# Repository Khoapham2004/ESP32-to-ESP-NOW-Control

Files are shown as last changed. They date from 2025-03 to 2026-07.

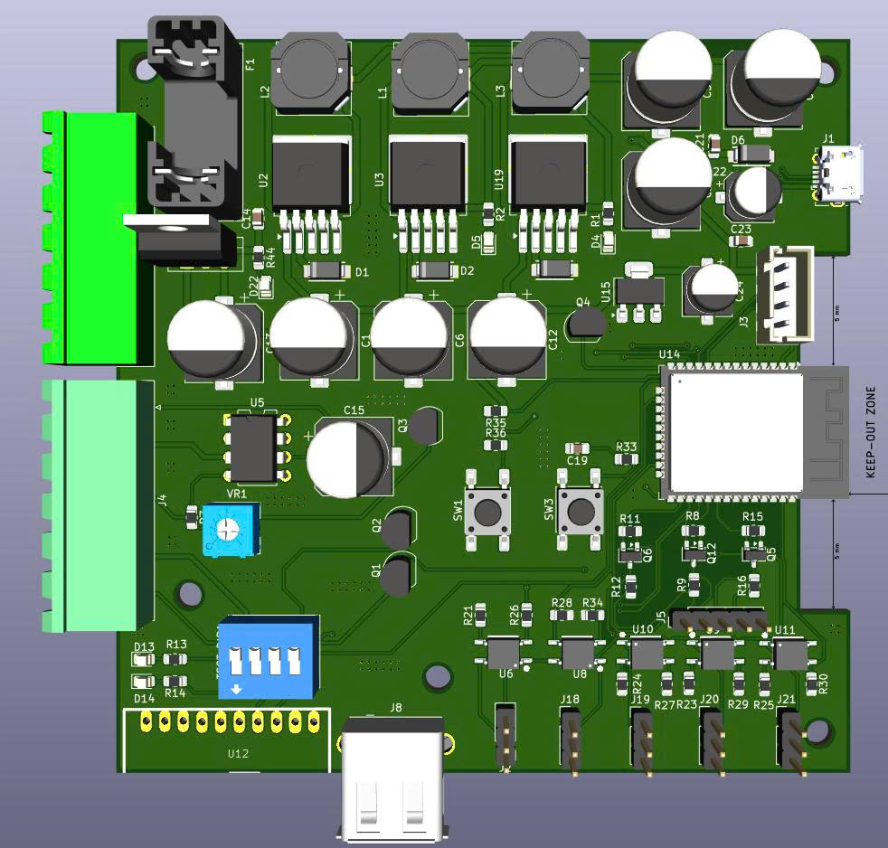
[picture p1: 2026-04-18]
EV_Smart_2026/RX_esp_now/pic1_RX.jpg

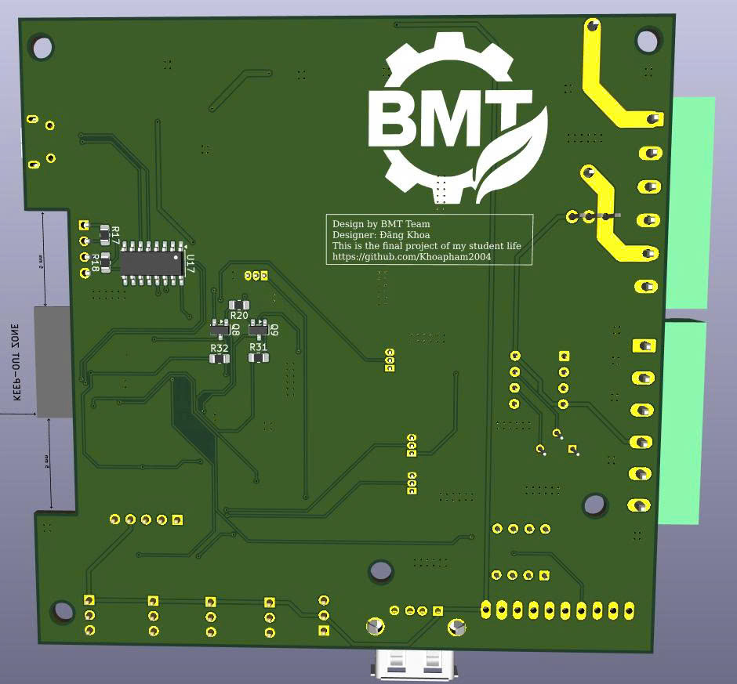
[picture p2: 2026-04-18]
EV_Smart_2026/RX_esp_now/pic2_RX.jpg

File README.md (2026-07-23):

The second repository contains the hardware design of the robot. It is mostly based on the 2025 version, with updated sensors, the BTS signal removed from the previous design, and a PCB that primarily uses SMD components for improved compactness and reliability.




The following slide presents the control board developed for the 2026 project.





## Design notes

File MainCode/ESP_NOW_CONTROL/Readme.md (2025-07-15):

1. Use source Get_ID_esp32.cpp get ID from esp receiver . Then we have a const ID EX: 00:4B:12:8E:79:D0.
2. Change the appropriate ID address in the transmission code.



Then Upload code for esp trans.

3. Upload again esp receiver by the esp_now_receive.cpp.
   
NOTE : 
+ if you want to know how it work you can visit file video.mp4 and circuit design in KICAD
+ This project is implemented on PlatformIO in VSCode, and the circuit is designed in KiCAD.
+ This project also have basic autonomous driving , basing on mpu6050 and ultrasonic sensor control steering system through 2 pid

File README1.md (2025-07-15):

# ESP32-to-ESP-NOW-Control
This project uses ESP-NOW communication between two ESP32 boards to control both a steering system and a motor. The sender reads input from a potentiometer (or joystick) and transmits the data wirelessly. The receiver processes the signals to adjust a servo motor for steering and control the speed and direction of a DC motor. The system ensures precise control by mapping the input values to appropriate ranges, with calibration adjustments for accurate steering and smooth motor operation.
If you want to learn more details, please watch the video.




  NOTE: 
  + Because when WiFi is enabled, only ADC1 can be used, so I cut the Lx wire from the joystick and re-soldered it to the output pin of the potentiometer on pin 32.(for trans circuit)
  + Due to some confusion, the circuit using the IC555 for the turn signal is not accurate. For the capacitor, a 110uF should be used, and the trigger pins should use TX2 and RX2 on the ESP32 pin 30.(for receiver circuit)
    


For the pre-built setups, I also integrated an autonomous vehicle with image processing using Python into the project.You can see the results in the video Autodriving-pythone.mp4, which also uses a Raspberry Pi.

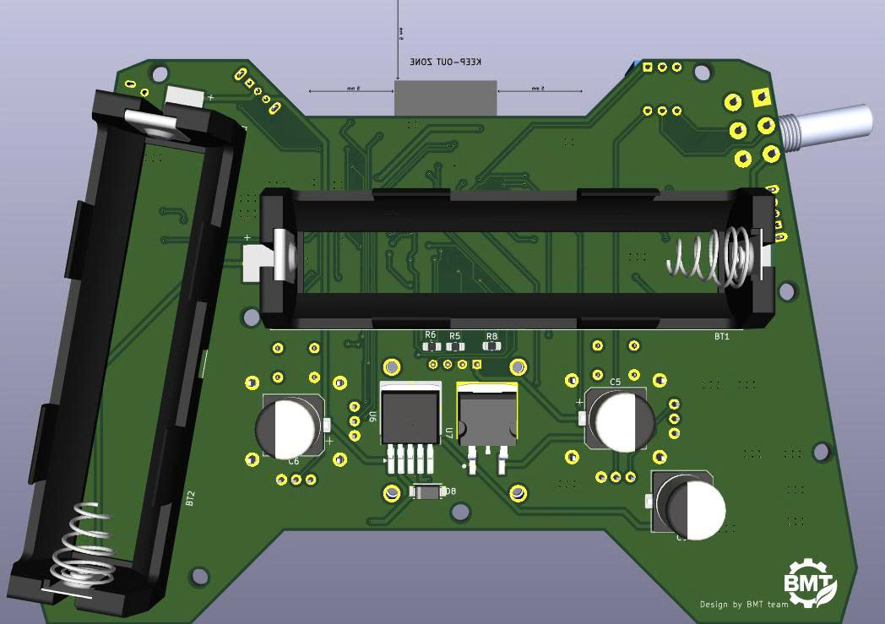
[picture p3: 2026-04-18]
EV_Smart_2026/TX_esp_now/pic2_TX.jpg

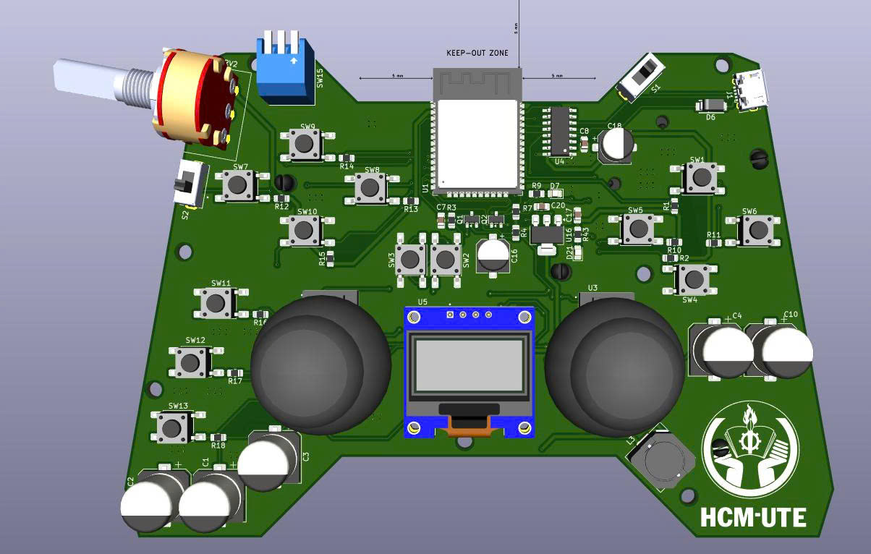
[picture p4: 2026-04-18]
EV_Smart_2026/TX_esp_now/pic1_TX.jpg

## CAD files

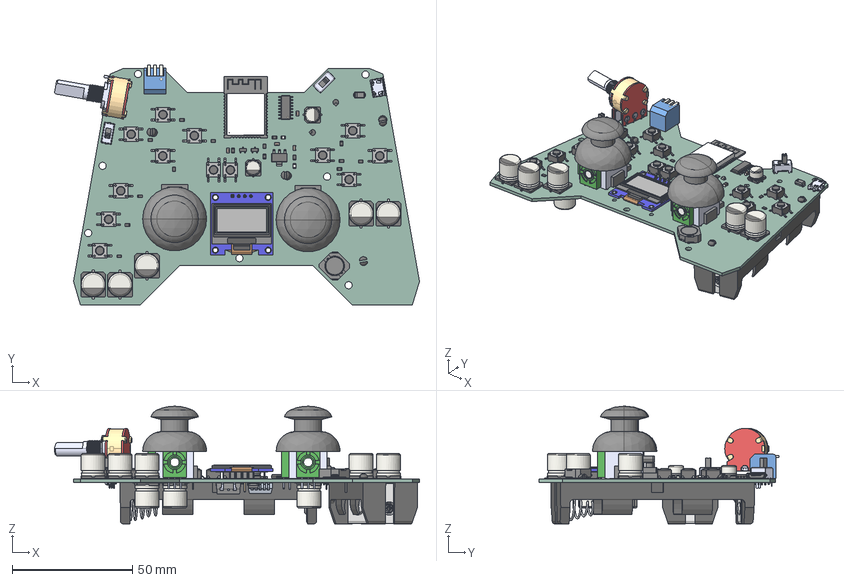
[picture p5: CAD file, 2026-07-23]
Control_PCB_2026/ps.step
152.1 x 100.1 x 49.0 mm
ESP32-WROOM-32D
CP_Elec_10x10.5 x 8
CDRH104R-100NC--3DModel-STEP-269445
10118194-0001LF--3DModel-STEP-269445
R_0805_2012Metric x 20
SW_DIP_SPSTx03_Piano_10.8x9.18mm_W7.62mm_P2.54mm
COM-09032 x 2
SW_Push_1P1T_NO_E-Switch_TL3301NxxxxxG x 13
SOT-23 x 2
CP_Elec_6.3x5.4 x 2
C_0805_2012Metric x 4
SOIC-16_3.9x9.9mm_P1.27mm
SS54-HF x 2
SS12D07VG4 x 2
SOT-223
DM-OLED096-636_Module
DM-OLED096-636_Panel
LED_0805_2012Metric x 2
KLS4-WH148-1B-4F-L20--3DModel-STEP-269445
L7805ACD2T-TR
ps 1.63.1
ps_PCB

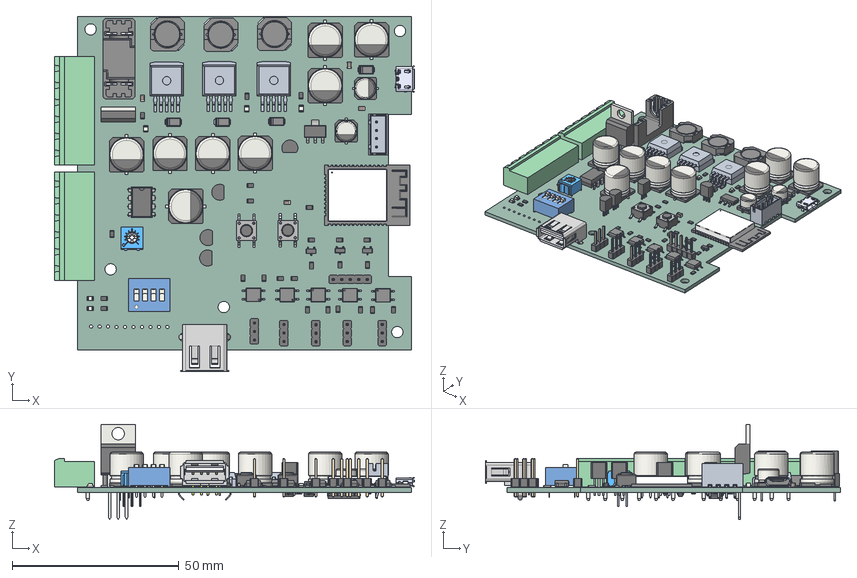
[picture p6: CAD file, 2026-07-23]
PCB_EV2026/ev_smart.step
107.9 x 106.5 x 28.5 mm
C_0805_2012Metric x 4
ev_smart 1.2
EL357N-G--3DModel-STEP-510211 x 5
R_0805_2012Metric x 30
TO-92_Inline x 4
CP_Elec_6.3x5.4 x 2
CP_Elec_10x10.5 x 8
ev_smart 1.13.1 x 3
LED_0805_2012Metric x 5
PinHeader_1x03_P2.54mm_Vertical x 5
ZX62D-B-5P8--3DModel-STEP-56544
ESP32-WROOM-32D
SS54-HF x 4
CDRH104R-100NC--3DModel-STEP-269445 x 3
SOT-23-3 x 3
PhoenixContact_MSTBA_2,5_6-G-5,08_1x06_P5.08mm_Horizontal x 2
USB-A-S-TH_S
USB-A-S-W-TH_B
USB-A-S-TH_P
PinHeader_1x05_P2.54mm_Vertical
TO-220-3_Vertical
SOT-223
DIP-8_W7.62mm
SW_Push_1P1T_NO_E-Switch_TL3301NxxxxxG x 2
3362P-1-105LF
SW_DIP_SPSTx04_Slide_9.78x12.34mm_W7.62mm_P2.54mm
SOIC-16_3.9x9.9mm_P1.27mm
SOT-23 x 2
ev_smart_PCB

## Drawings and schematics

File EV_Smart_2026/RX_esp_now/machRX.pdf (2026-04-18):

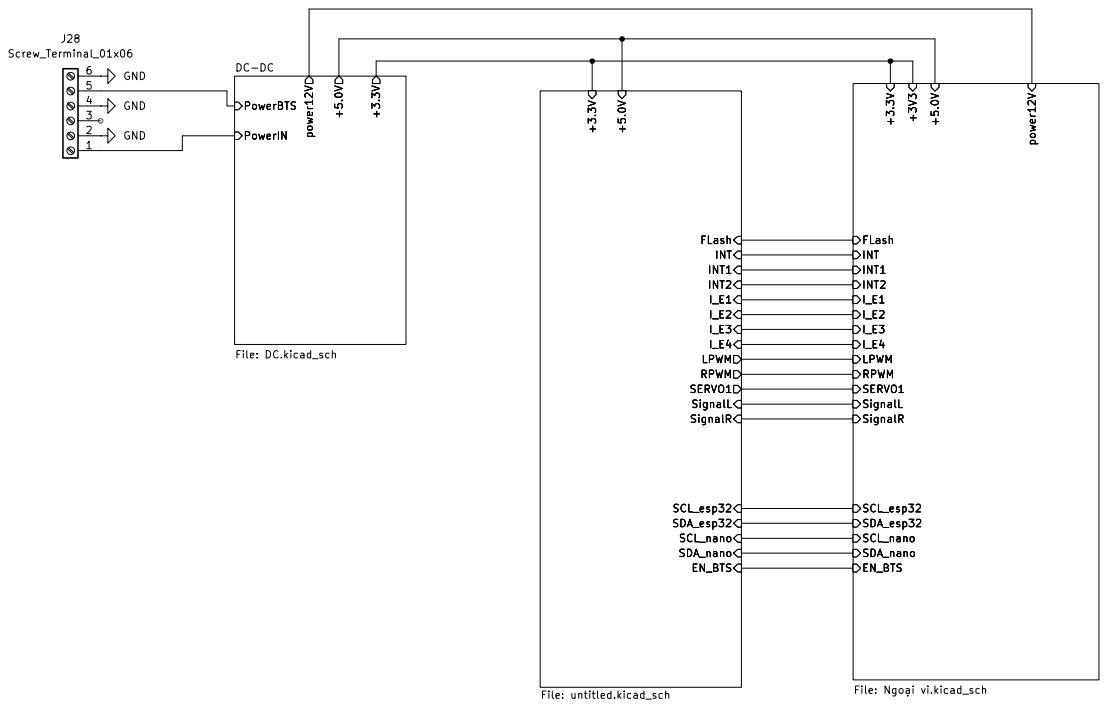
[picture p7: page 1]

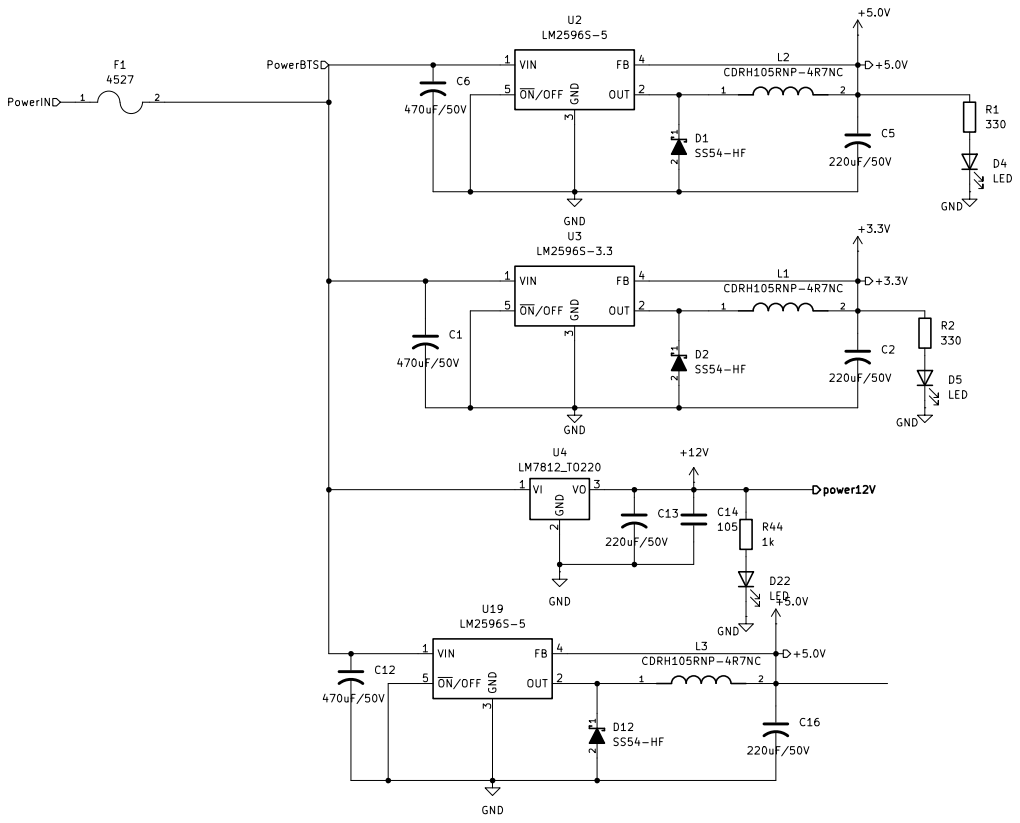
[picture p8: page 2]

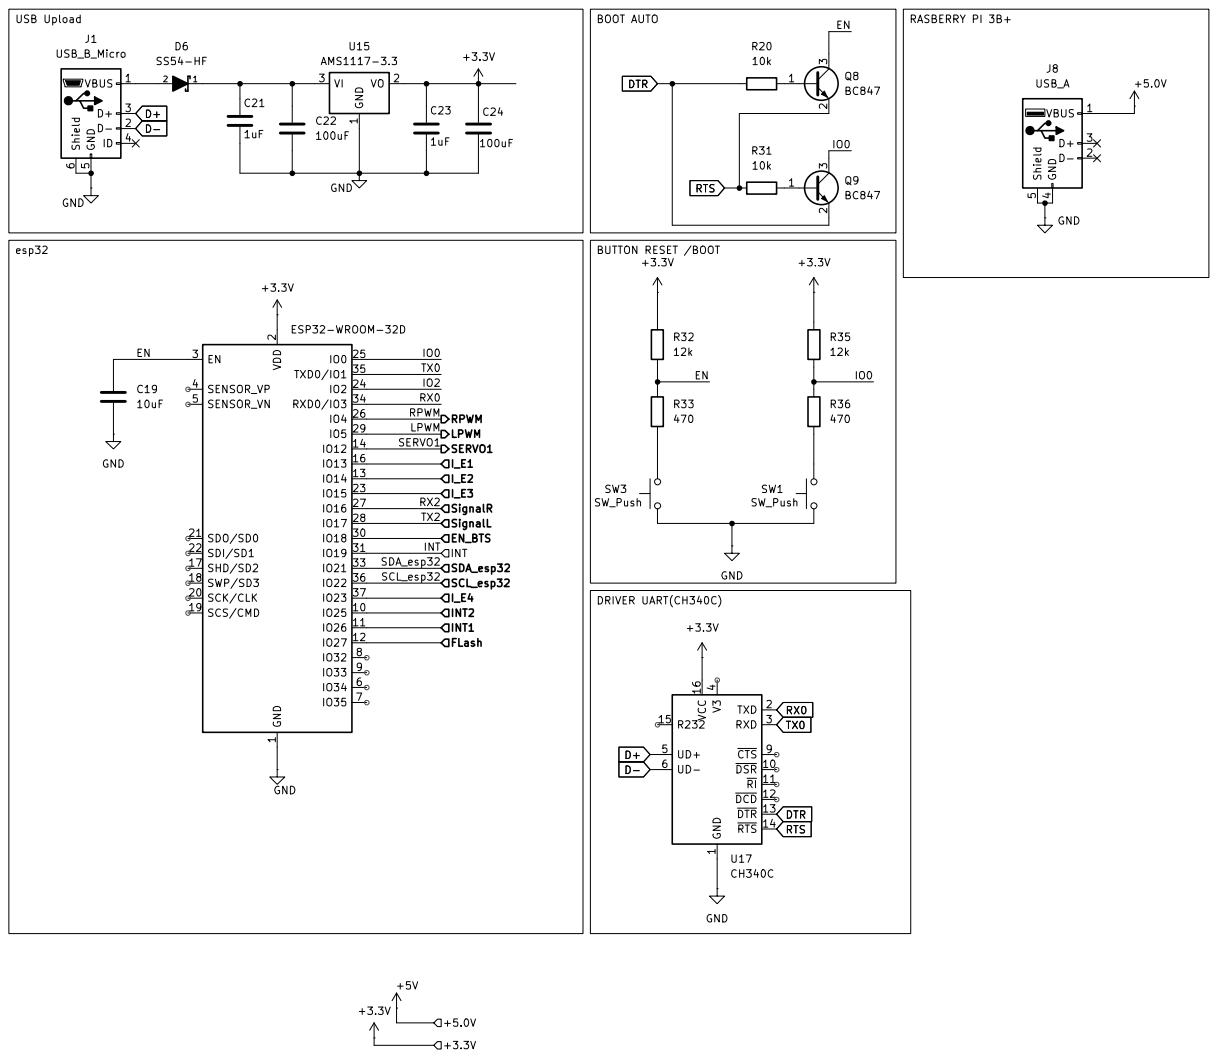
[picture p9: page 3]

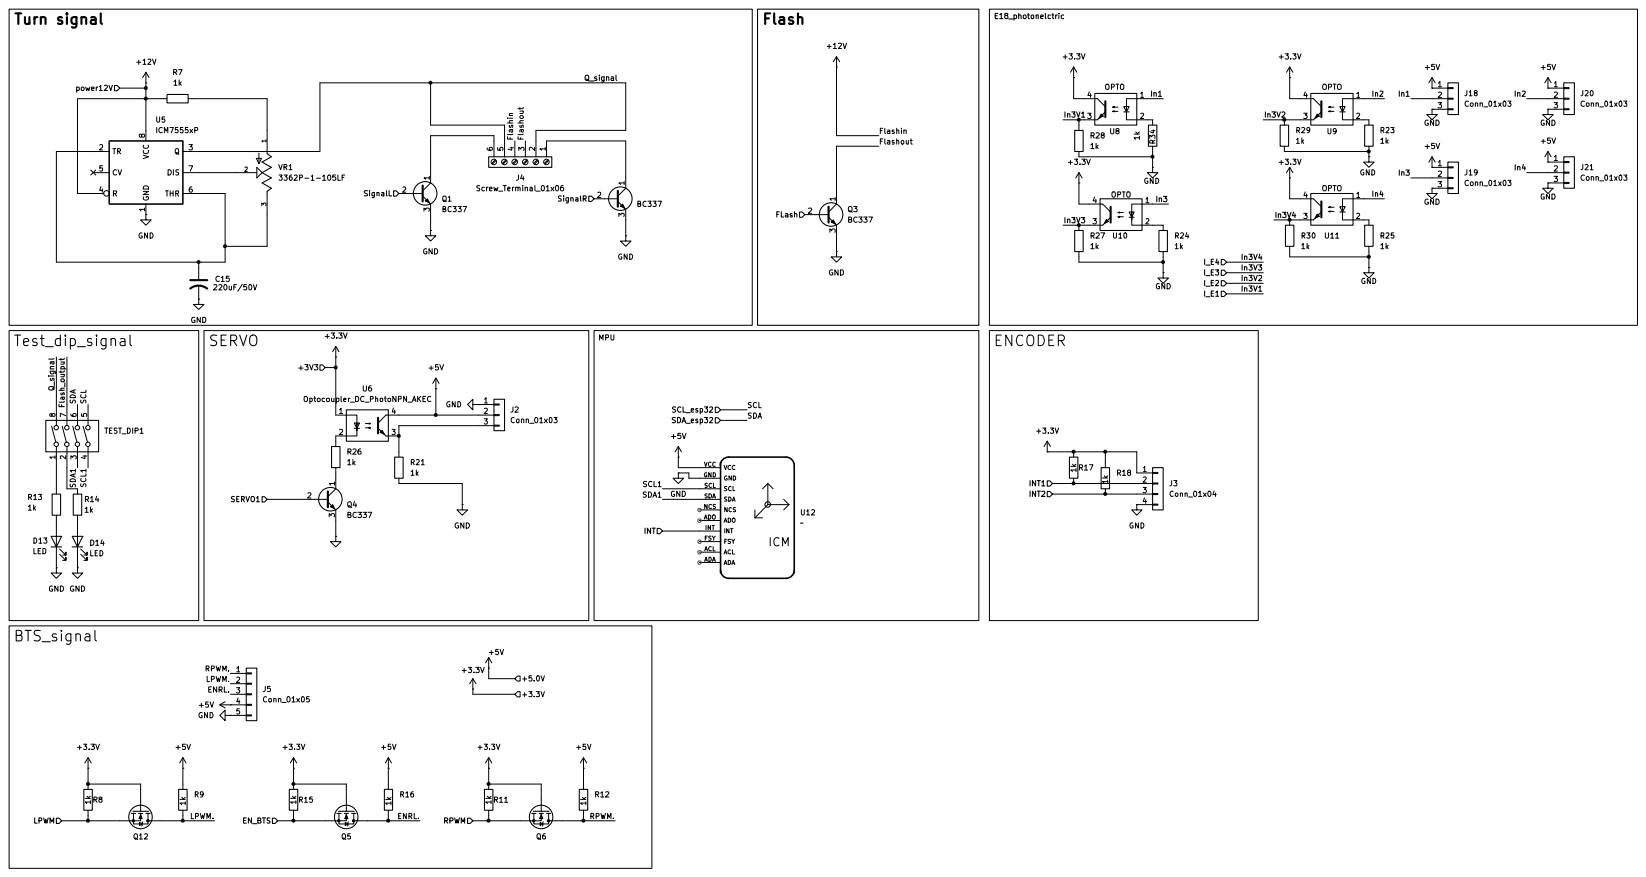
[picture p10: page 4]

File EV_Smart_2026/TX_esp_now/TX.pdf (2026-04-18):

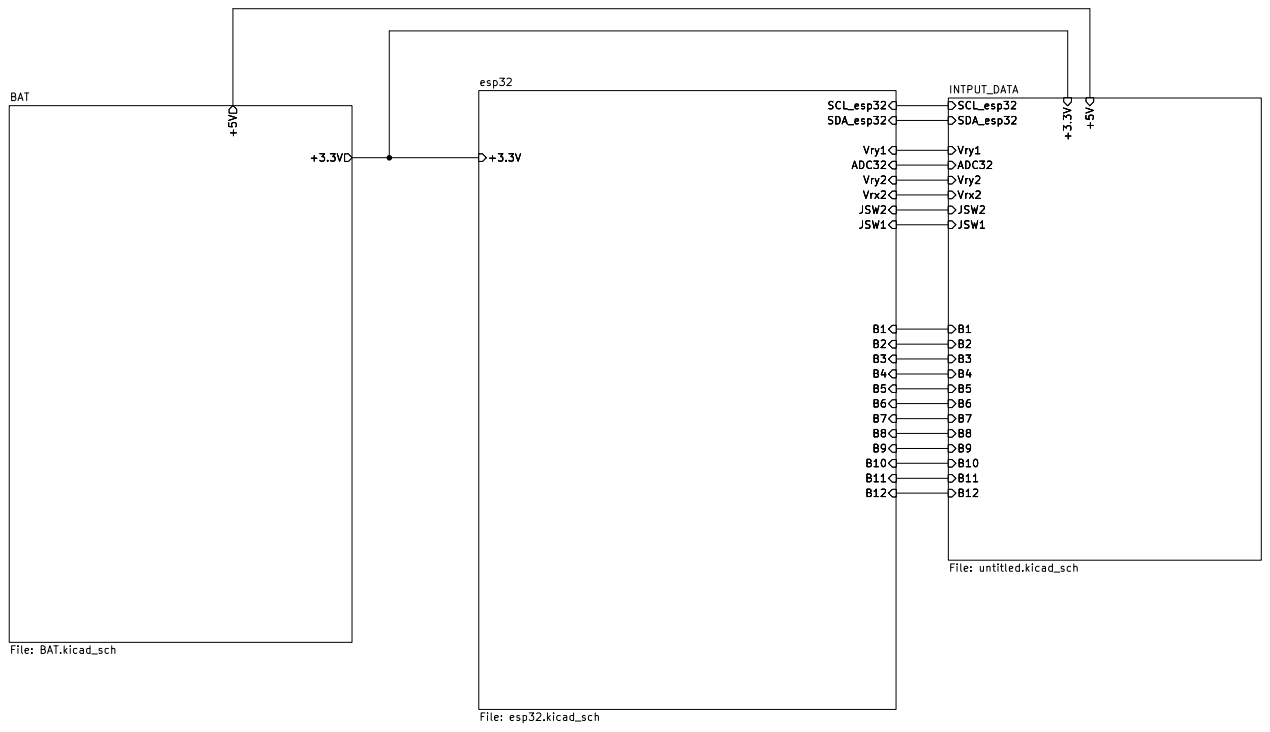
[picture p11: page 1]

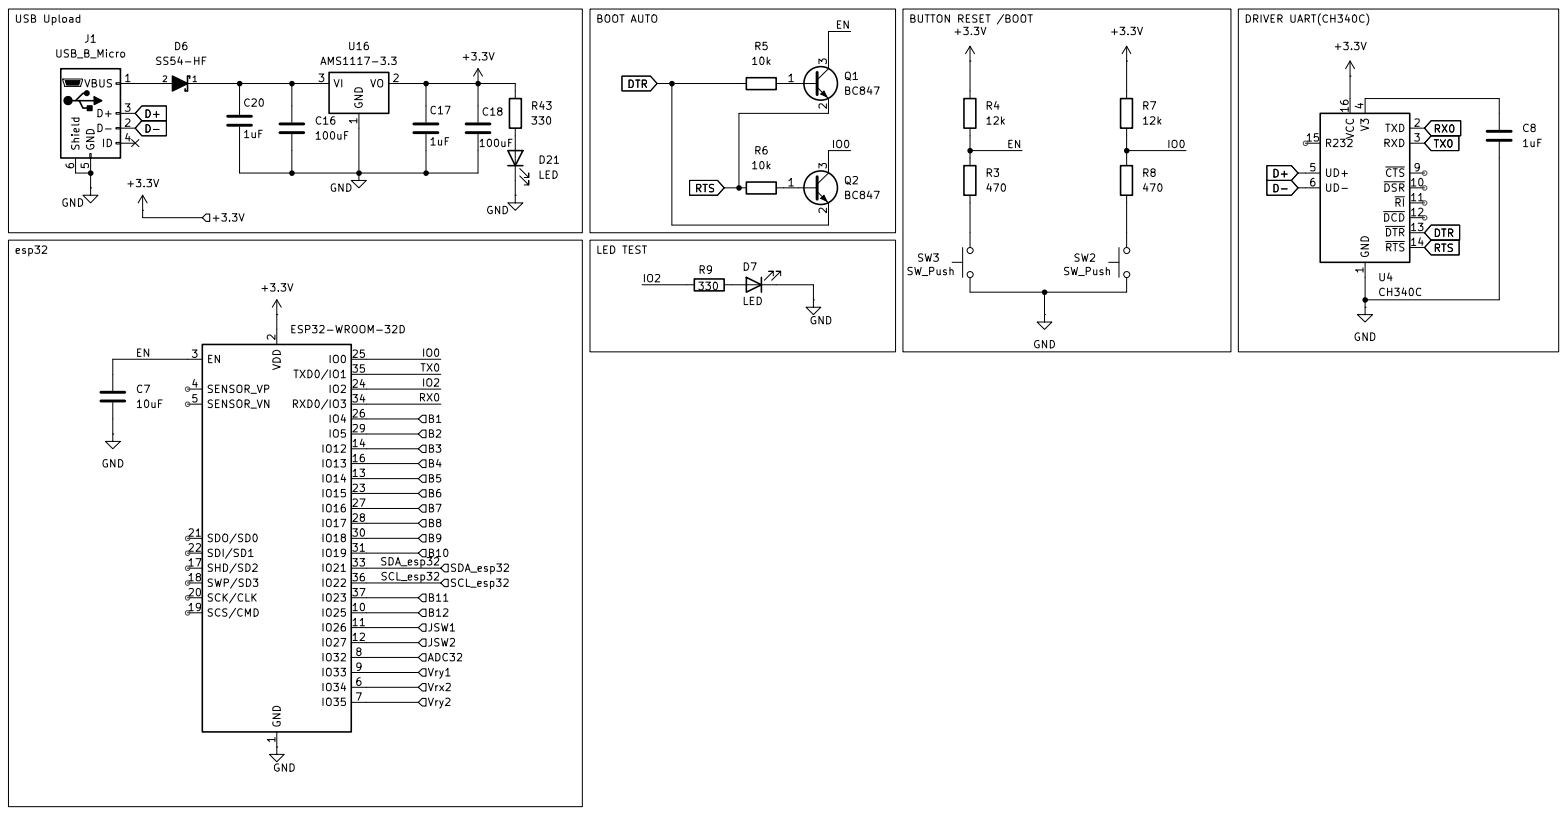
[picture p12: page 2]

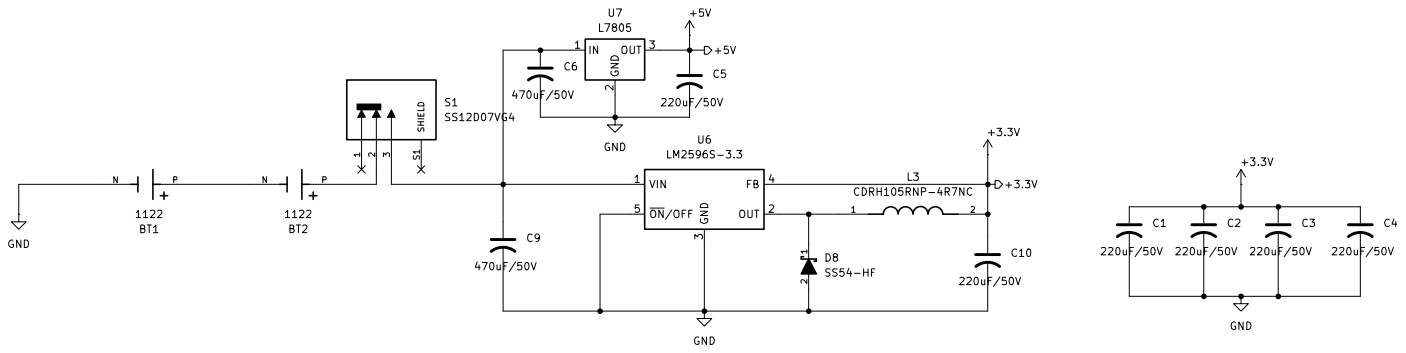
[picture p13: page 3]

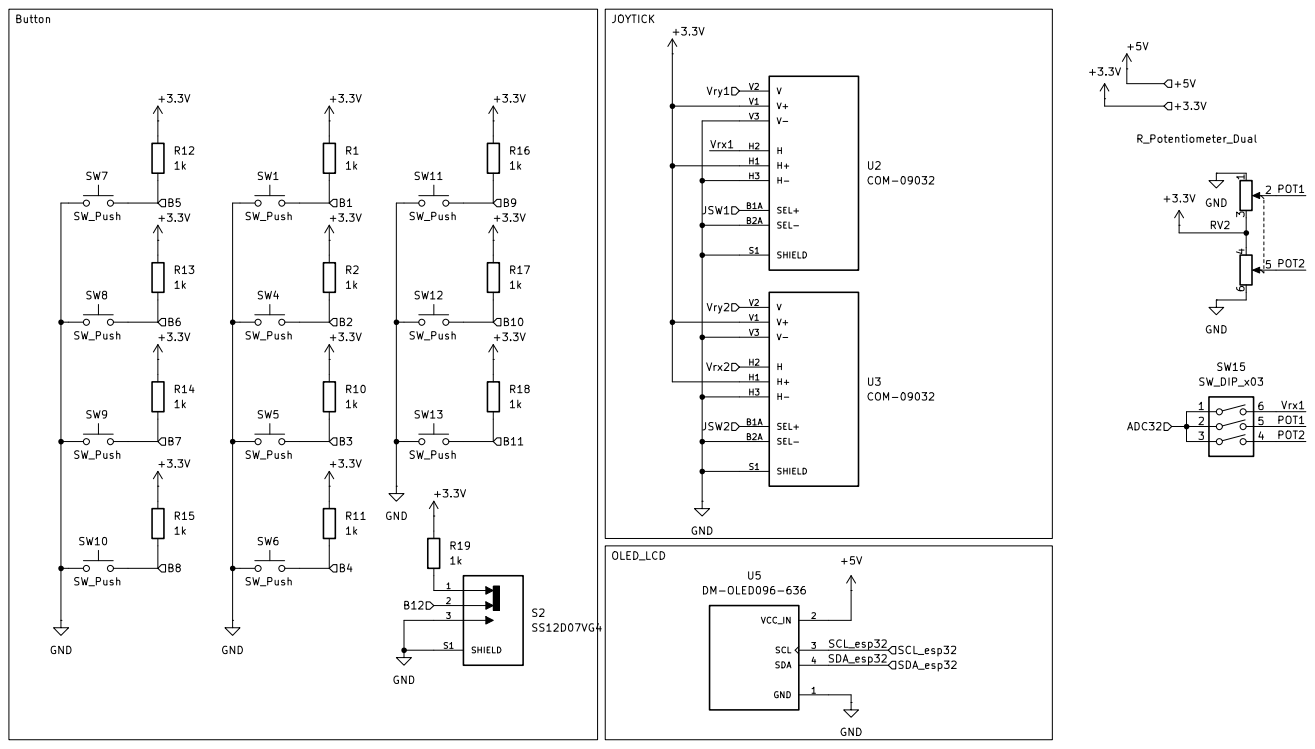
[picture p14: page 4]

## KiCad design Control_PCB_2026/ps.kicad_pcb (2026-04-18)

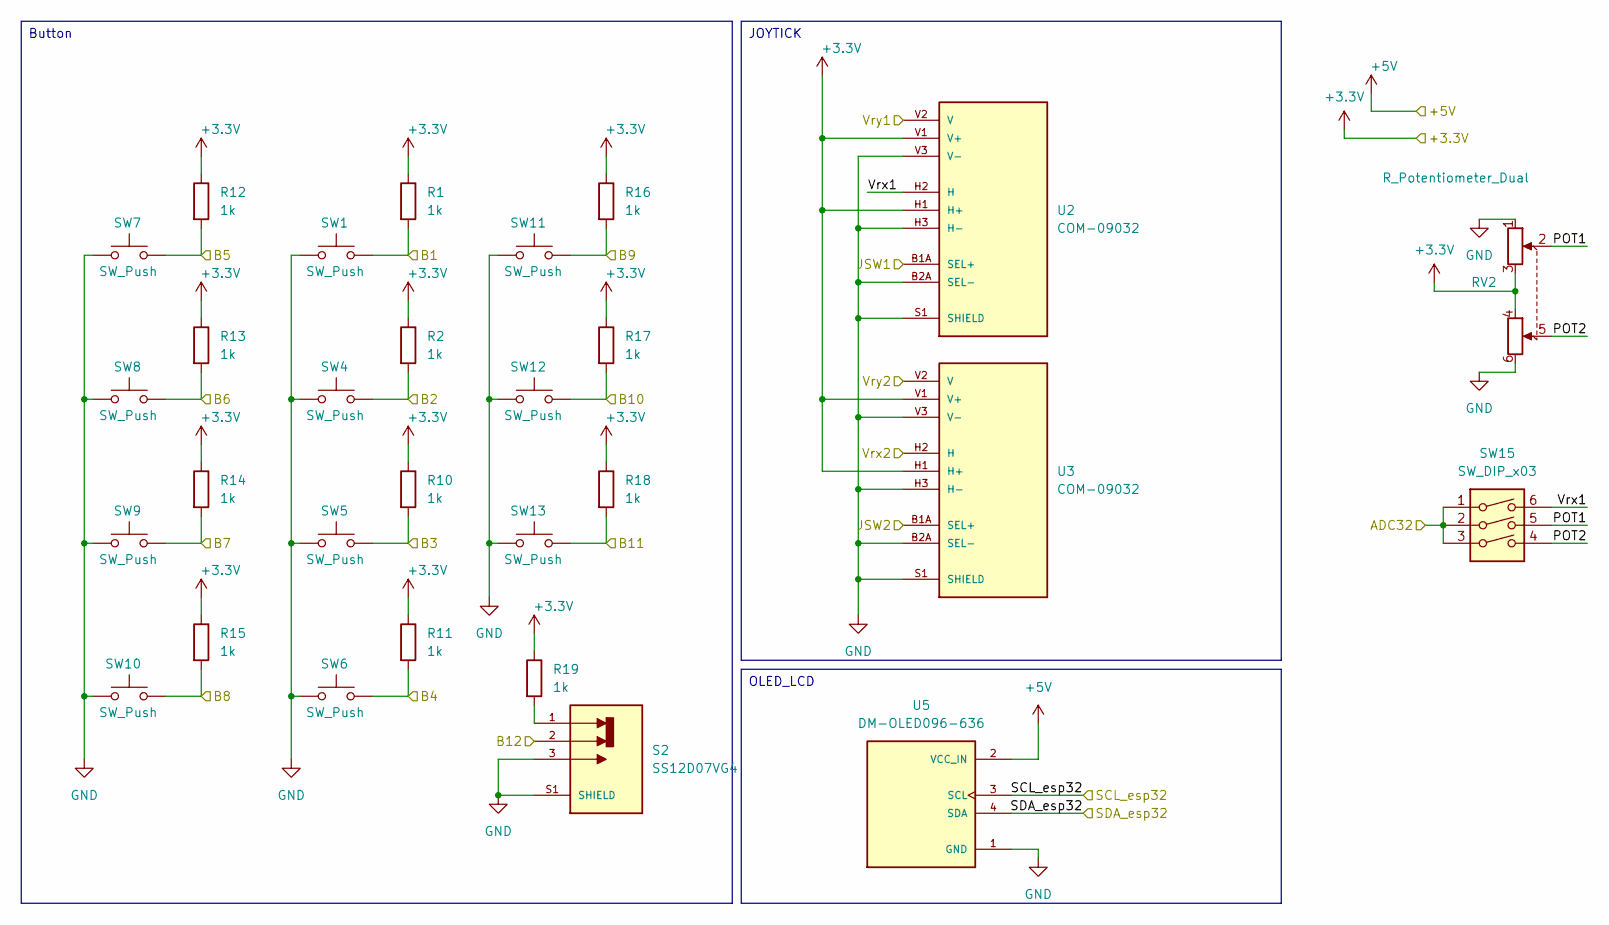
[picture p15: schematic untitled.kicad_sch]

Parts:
R1, R2, R10, R11, R12, R13, R14, R15, R16, R17, R18, R19: 1k; R_0805_2012Metric_Pad1.20x1.40mm_HandSolder
RV2: R_Potentiometer_Dual; Potentiometer_Alps_RK163_Dual_Horizontal
S2: SS12D07VG4; SW_SS12D07VG4; PARTREV 1
SW1, SW4, SW5, SW6, SW7, SW8, SW9, SW10, SW11, SW12, SW13: SW_Push; SW_Push_1P1T_NO_E-Switch_TL3301NxxxxxG
SW15: SW_DIP_x03; SW_DIP_SPSTx03_Piano_10.8x9.18mm_W7.62mm_P2.54mm
U2, U3: COM-09032; XDCR_COM-09032; PARTREV N/A
U5: DM-OLED096-636; MODULE_DM-OLED096-636; PARTREV 2018-09-10

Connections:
+3.3V: R1.1, R2.1, R10.1, R11.1, R12.1, R13.1, R14.1, R15.1, R16.1, R17.1, R18.1, R19.1, RV2.3, RV2.4, U2.H1 (H+), U2.V1 (V+), U3.H1 (H+), U3.V1 (V+); also elsewhere on the board
+5V: U5.2 (VCC_IN); also elsewhere on the board
/INTPUT_DATA/ADC32: SW15.1, SW15.2, SW15.3; also elsewhere on the board
/INTPUT_DATA/B1: R1.2, SW1.2; also elsewhere on the board
/INTPUT_DATA/B2: R2.2, SW4.2; also elsewhere on the board
/INTPUT_DATA/B3: R10.2, SW5.2; also elsewhere on the board
/INTPUT_DATA/B4: R11.2, SW6.2; also elsewhere on the board
/INTPUT_DATA/B5: R12.2, SW7.2; also elsewhere on the board
/INTPUT_DATA/B6: R13.2, SW8.2; also elsewhere on the board
/INTPUT_DATA/B7: R14.2, SW9.2; also elsewhere on the board
/INTPUT_DATA/B8: R15.2, SW10.2; also elsewhere on the board
/INTPUT_DATA/B9: R16.2, SW11.2; also elsewhere on the board
/INTPUT_DATA/B10: R17.2, SW12.2; also elsewhere on the board
/INTPUT_DATA/B11: R18.2, SW13.2; also elsewhere on the board
/INTPUT_DATA/B12: S2.2; also elsewhere on the board
/INTPUT_DATA/JSW1: U2.B1A (SEL+); also elsewhere on the board
/INTPUT_DATA/JSW2: U3.B1A (SEL+); also elsewhere on the board
/INTPUT_DATA/POT1: RV2.2, SW15.5
/INTPUT_DATA/POT2: RV2.5, SW15.4
/INTPUT_DATA/SCL_esp32: U5.3 (SCL); also elsewhere on the board
/INTPUT_DATA/SDA_esp32: U5.4 (SDA); also elsewhere on the board
/INTPUT_DATA/Vrx1: SW15.6, U2.H2 (H)
/INTPUT_DATA/Vrx2: U3.H2 (H); also elsewhere on the board
/INTPUT_DATA/Vry1: U2.V2 (V); also elsewhere on the board
/INTPUT_DATA/Vry2: U3.V2 (V); also elsewhere on the board
GND: RV2.1, RV2.6, S2.3, S2.S1 (SHIELD), S2.S2 (SHIELD), SW1.1, SW4.1, SW5.1, SW6.1, SW7.1, SW8.1, SW9.1, SW10.1, SW11.1, SW12.1, SW13.1, U2.B2A (SEL-), U2.H3 (H-), U2.S1 (SHIELD), U2.S2 (SHIELD), U2.S3 (SHIELD), U2.S4 (SHIELD), U2.V3 (V-), U3.B2A (SEL-), U3.H3 (H-), U3.S1 (SHIELD), U3.S2 (SHIELD), U3.S3 (SHIELD), U3.S4 (SHIELD), U3.V3 (V-), U5.1 (GND); also elsewhere on the board
unnamed: R19.2, S2.1

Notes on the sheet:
OLED_LCD
Button
JOYTICK

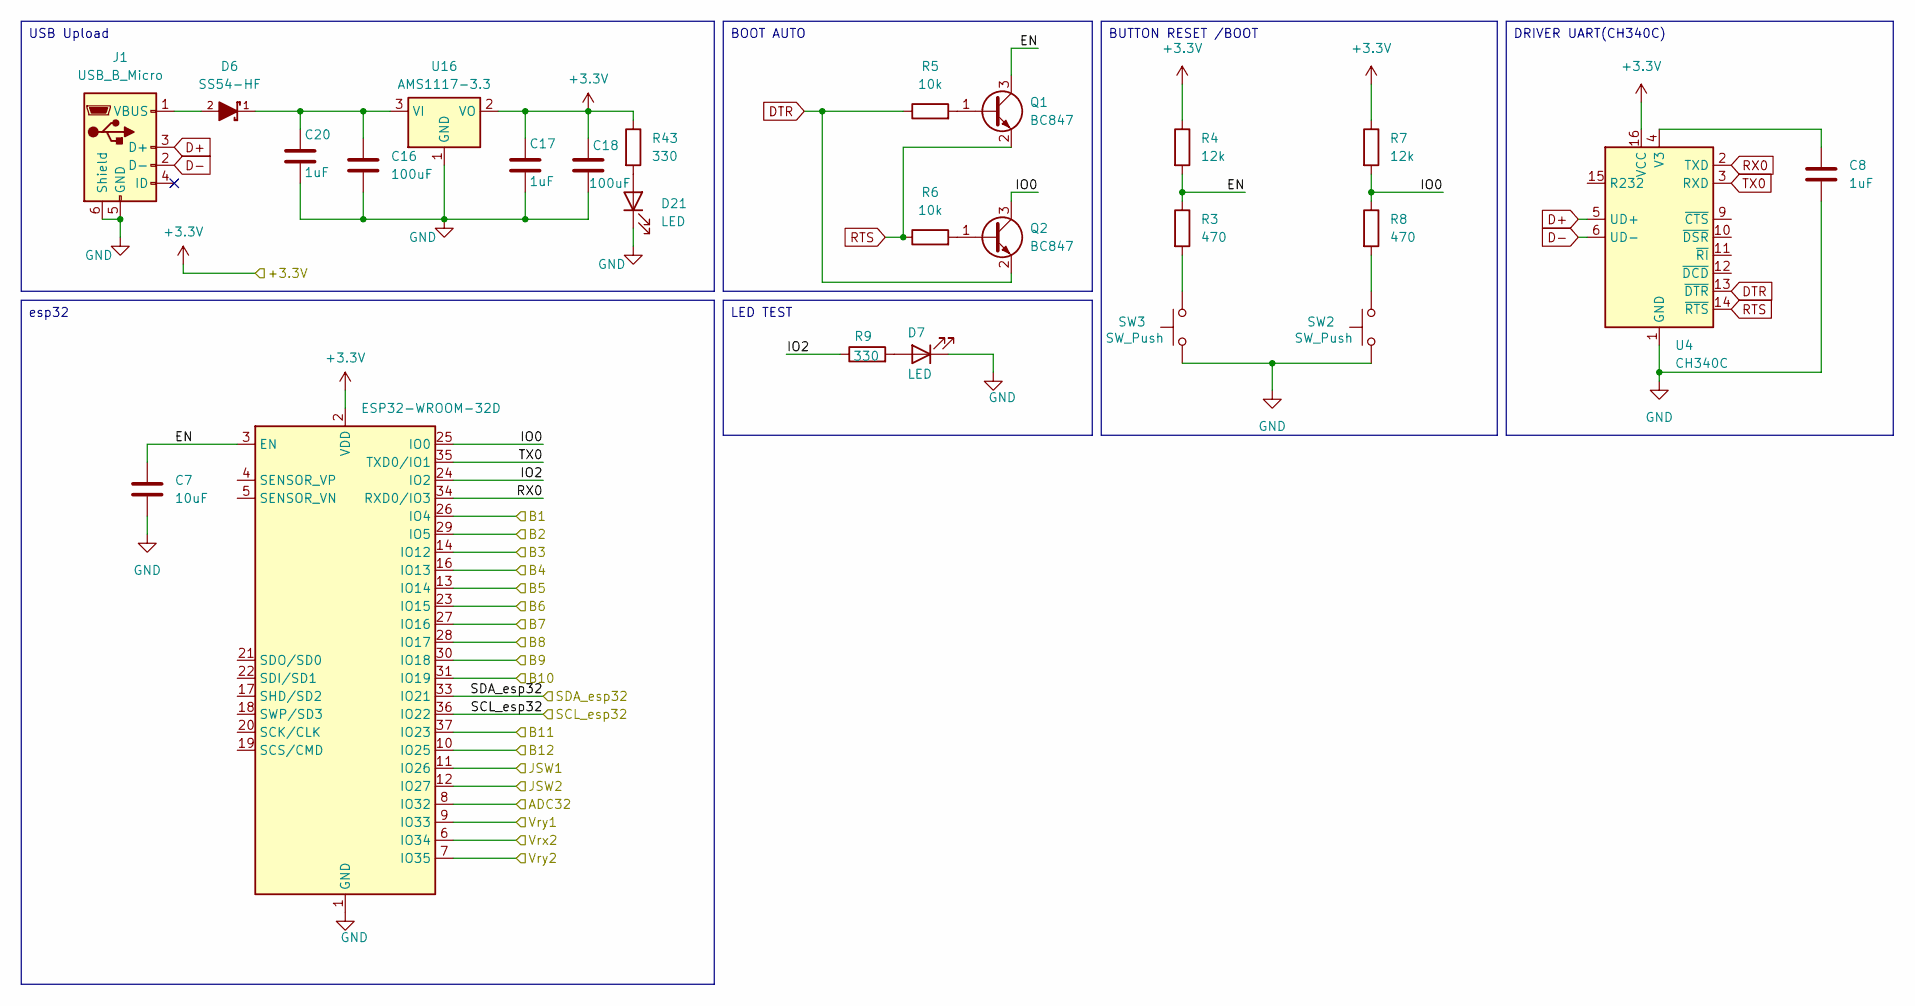
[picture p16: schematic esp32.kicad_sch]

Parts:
C7: 10uF; C_0805_2012Metric_Pad1.18x1.45mm_HandSolder
C8, C17, C20: 1uF; C_0805_2012Metric_Pad1.18x1.45mm_HandSolder
C16, C18: 100uF; CP_Elec_6.3x5.4
D6: SS54-HF; DIOM5025X220N; MOUSER_PART_NUMBER 750-SS54-HF
D7, D21: LED; LED_0805_2012Metric
J1: USB_B_Micro; USB_Micro-B_Molex-105017-0001
Q1, Q2: BC847; SOT-23
R3, R8: 470; R_0805_2012Metric_Pad1.20x1.40mm_HandSolder
R4, R7: 12k; R_0805_2012Metric_Pad1.20x1.40mm_HandSolder
R5, R6: 10k; R_0805_2012Metric_Pad1.20x1.40mm_HandSolder
R9, R43: 330; R_0805_2012Metric_Pad1.20x1.40mm_HandSolder
SW2, SW3: SW_Push; SW_Push_1P1T_NO_E-Switch_TL3301NxxxxxG
U1: ESP32-WROOM-32D
U4: CH340C; SOIC-16_3.9x9.9mm_P1.27mm
U16: AMS1117-3.3; SOT-223-3_TabPin2

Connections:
+3.3V: C17.1, C18.1, R4.1, R7.1, R43.1, U1.2 (VDD), U4.16 (VCC), U16.2 (VO); also elsewhere on the board
/INTPUT_DATA/ADC32: U1.8 (IO32); also elsewhere on the board
/INTPUT_DATA/B1: U1.26 (IO4); also elsewhere on the board
/INTPUT_DATA/B2: U1.29 (IO5); also elsewhere on the board
/INTPUT_DATA/B3: U1.14 (IO12); also elsewhere on the board
/INTPUT_DATA/B4: U1.16 (IO13); also elsewhere on the board
/INTPUT_DATA/B5: U1.13 (IO14); also elsewhere on the board
/INTPUT_DATA/B6: U1.23 (IO15); also elsewhere on the board
/INTPUT_DATA/B7: U1.27 (IO16); also elsewhere on the board
/INTPUT_DATA/B8: U1.28 (IO17); also elsewhere on the board
/INTPUT_DATA/B9: U1.30 (IO18); also elsewhere on the board
/INTPUT_DATA/B10: U1.31 (IO19); also elsewhere on the board
/INTPUT_DATA/B11: U1.37 (IO23); also elsewhere on the board
/INTPUT_DATA/B12: U1.10 (IO25); also elsewhere on the board
/INTPUT_DATA/JSW1: U1.11 (IO26); also elsewhere on the board
/INTPUT_DATA/JSW2: U1.12 (IO27); also elsewhere on the board
/INTPUT_DATA/SCL_esp32: U1.36 (IO22); also elsewhere on the board
/INTPUT_DATA/SDA_esp32: U1.33 (IO21); also elsewhere on the board
/INTPUT_DATA/Vrx2: U1.6 (IO34); also elsewhere on the board
/INTPUT_DATA/Vry1: U1.9 (IO33); also elsewhere on the board
/INTPUT_DATA/Vry2: U1.7 (IO35); also elsewhere on the board
/esp32/EN: C7.1, Q1.3 (C), R3.1, R4.2, U1.3 (EN)
/esp32/IO0: Q2.3 (C), R7.2, R8.1, U1.25 (IO0)
/esp32/IO2: R9.1, U1.24 (IO2)
D+: J1.3 (D+), U4.5 (UD+)
D-: J1.2 (D-), U4.6 (UD-)
DTR: Q2.2 (E), R5.1, U4.13 (~DTR)
GND: C7.2, C8.2, C16.2, C17.2, C18.2, C20.2, D7.1 (K), D21.1 (K), J1.5 (GND), J1.6 (Shield), SW2.1, SW3.1, U1.1 (GND), U1.15 (GND), U1.38 (GND), U1.39 (GND), U4.1 (GND), U16.1 (GND); also elsewhere on the board
unnamed: D7.2 (A), R9.2
unnamed: D21.2 (A), R43.2
unnamed: D6.2, J1.1 (VBUS)
unnamed: Q1.1 (B), R5.2
unnamed: Q2.1 (B), R6.2
unnamed: R3.2, SW3.2
unnamed: R8.2, SW2.2
unnamed: C8.1, U4.4 (V3)
unnamed: C16.1, C20.1, D6.1, U16.3 (VI)
RTS: Q1.2 (E), R6.1, U4.14 (~RTS)
RX0: U1.34 (RXD0/IO3), U4.2 (TXD)
TX0: U1.35 (TXD0/IO1), U4.3 (RXD)

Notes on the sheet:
esp32
USB Upload
DRIVER UART(CH340C)
LED TEST
BUTTON RESET /BOOT
BOOT AUTO

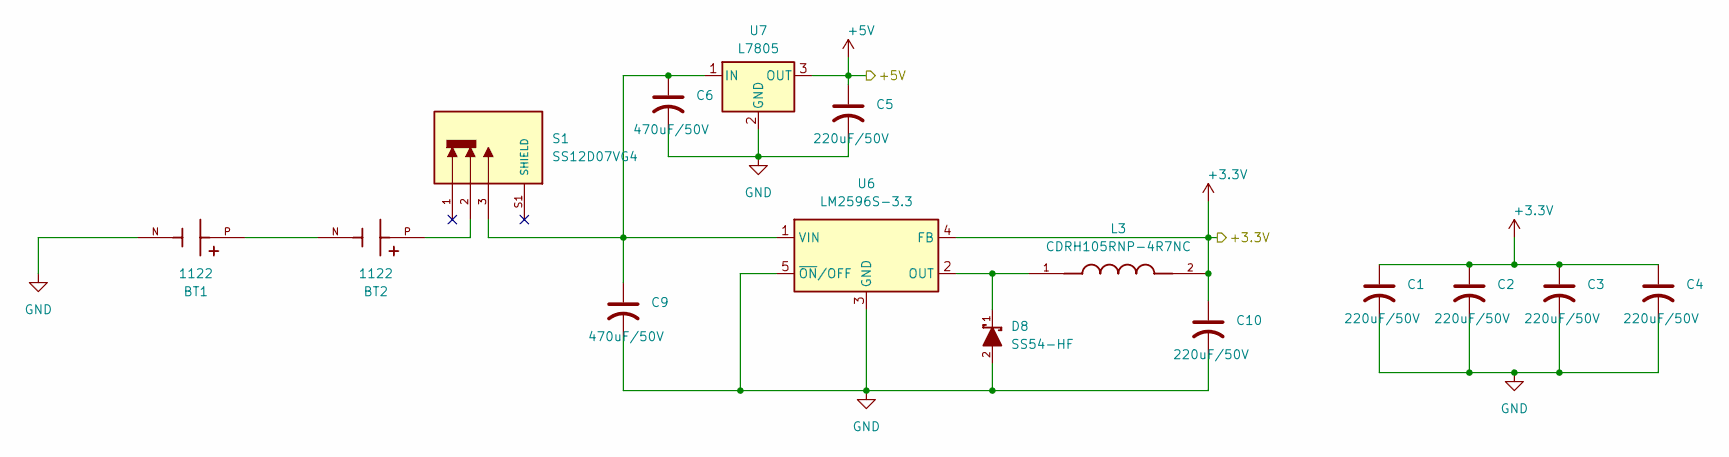
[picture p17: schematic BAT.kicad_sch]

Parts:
BT1, BT2: 1122; BAT_1122; PARTREV B
C1, C2, C3, C4, C5, C10: 220uF/50V; CP_Elec_10x10.5
C6, C9: 470uF/50V; CP_Elec_10x10.5
D8: SS54-HF; DIOM5025X220N; MOUSER_PART_NUMBER 750-SS54-HF
L3: CDRH105RNP-4R7NC; IND_CDRH105RNP-4R7NC; PARTREV 23-Oct-2017
S1: SS12D07VG4; SW_SS12D07VG4; PARTREV 1
U6: LM2596S-3.3; TO-263-5_TabPin3
U7: L7805; TO254P1515X470-3N

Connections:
+3.3V: C1.1, C2.1, C3.1, C4.1, C10.1, L3.2, U6.4 (FB); also elsewhere on the board
+5V: C5.1, U7.3 (OUT); also elsewhere on the board
GND: BT1.N, C1.2, C2.2, C3.2, C4.2, C5.2, C6.2, C9.2, C10.2, D8.2, U6.3 (GND), U6.5 (~ON/OFF), U7.2 (GND); also elsewhere on the board
unnamed: BT1.P, BT2.N
unnamed: BT2.P, S1.2
unnamed: D8.1, L3.1, U6.2 (OUT)
unnamed: C6.1, C9.1, S1.3, U6.1 (VIN), U7.1 (IN)

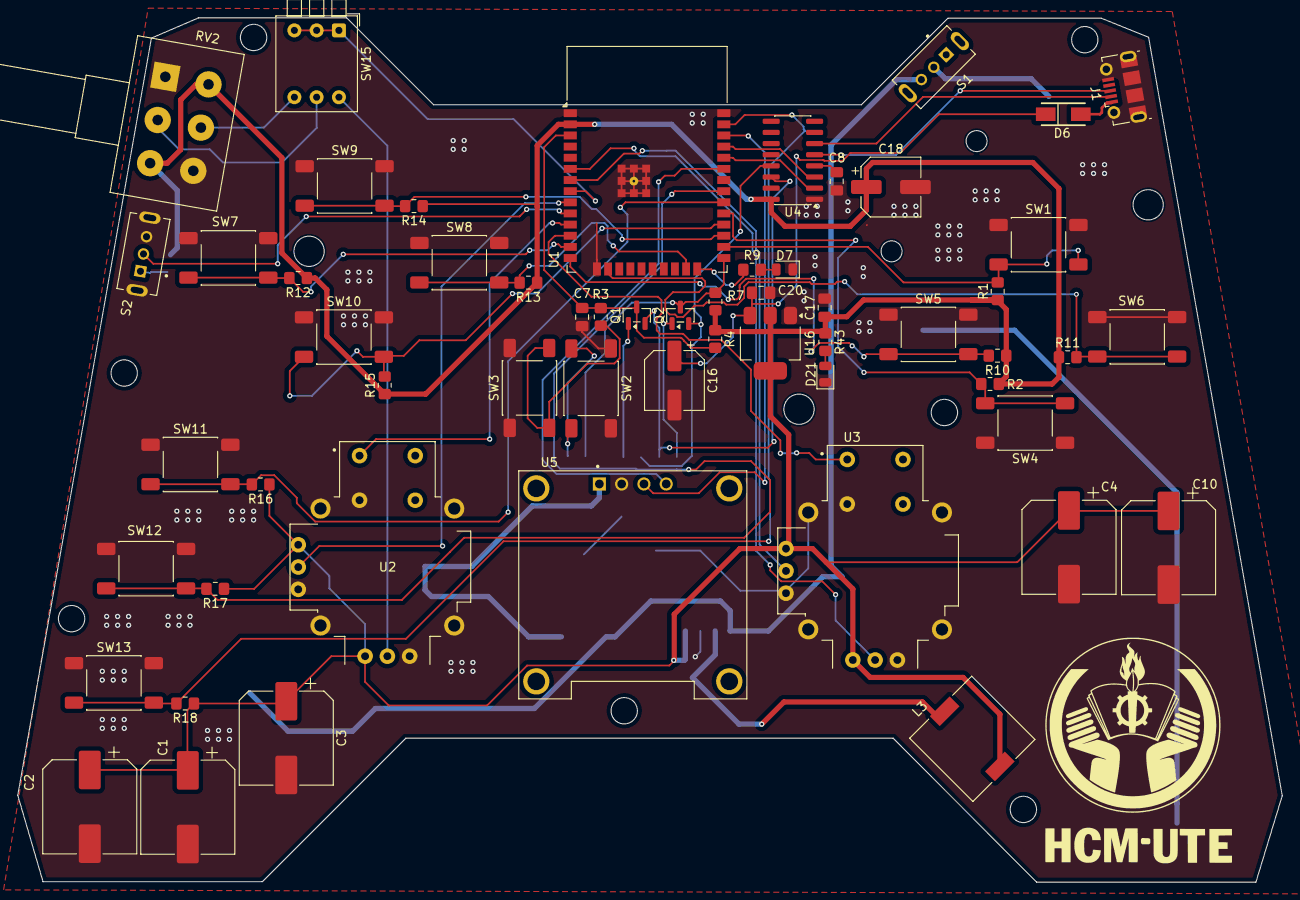
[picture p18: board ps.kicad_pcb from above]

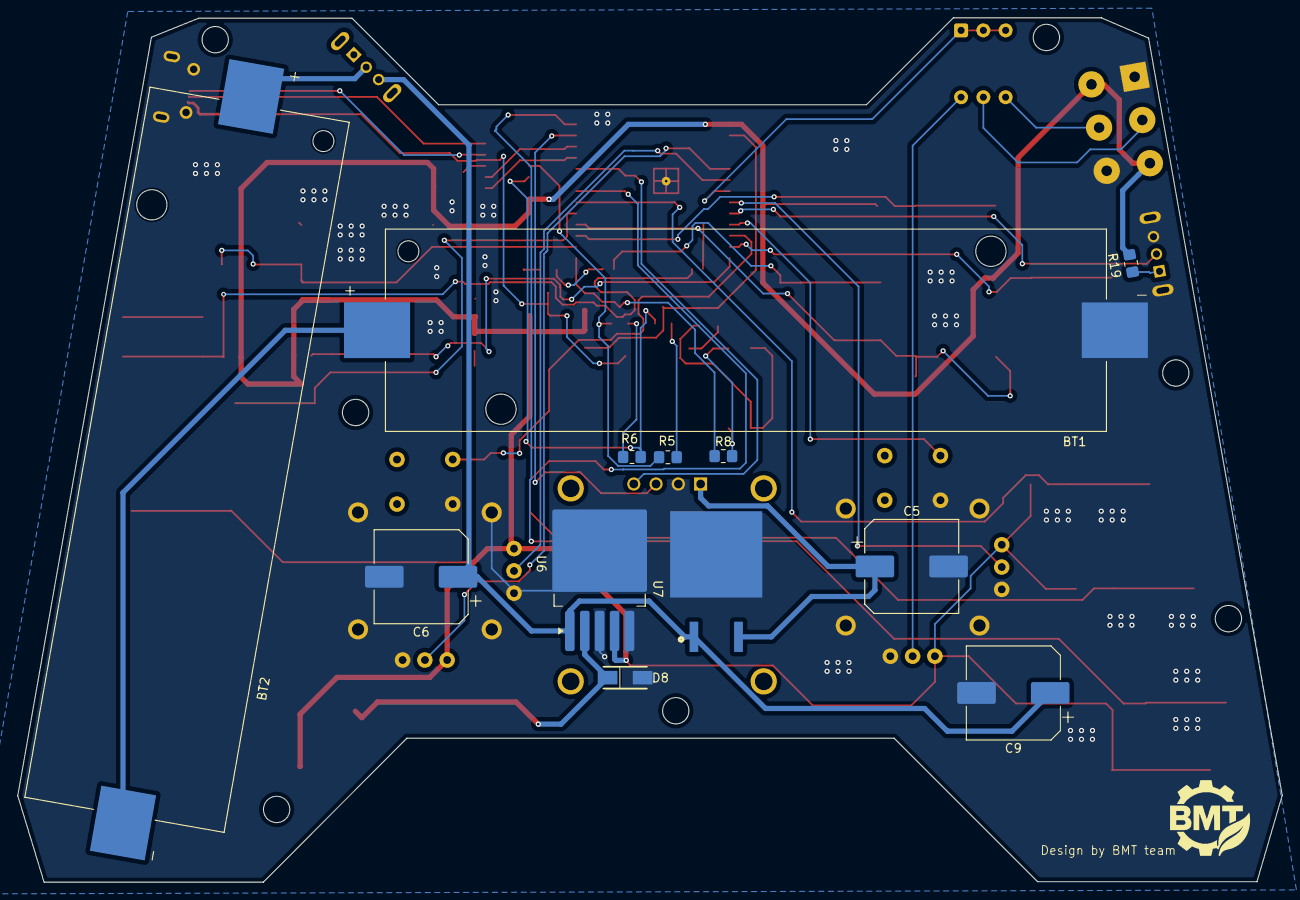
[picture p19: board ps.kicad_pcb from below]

Board: 2 copper layers, 144.1 x 98.5 mm, 69 parts (12 on the bottom side), 49 nets.

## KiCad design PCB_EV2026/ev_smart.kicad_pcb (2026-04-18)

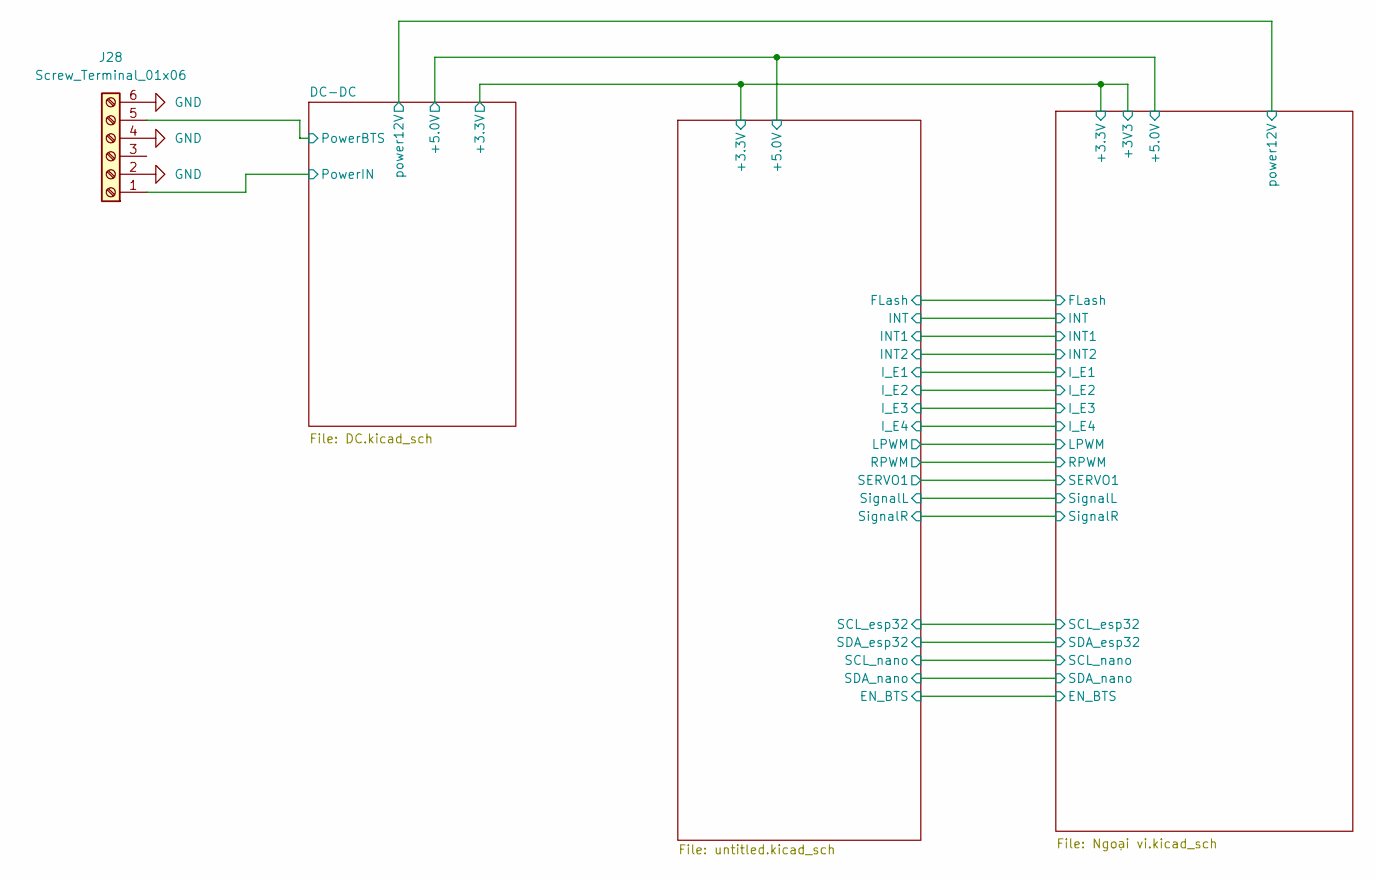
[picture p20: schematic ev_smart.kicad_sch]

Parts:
J28: Screw_Terminal_01x06; PhoenixContact_MSTBA_2,5_6-G-5,08_1x06_P5.08mm_Horizontal

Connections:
/DC-DC/PowerBTS: J28.5; also elsewhere on the board
/DC-DC/PowerIN: J28.1; also elsewhere on the board
GND: J28.2, J28.4, J28.6; also elsewhere on the board

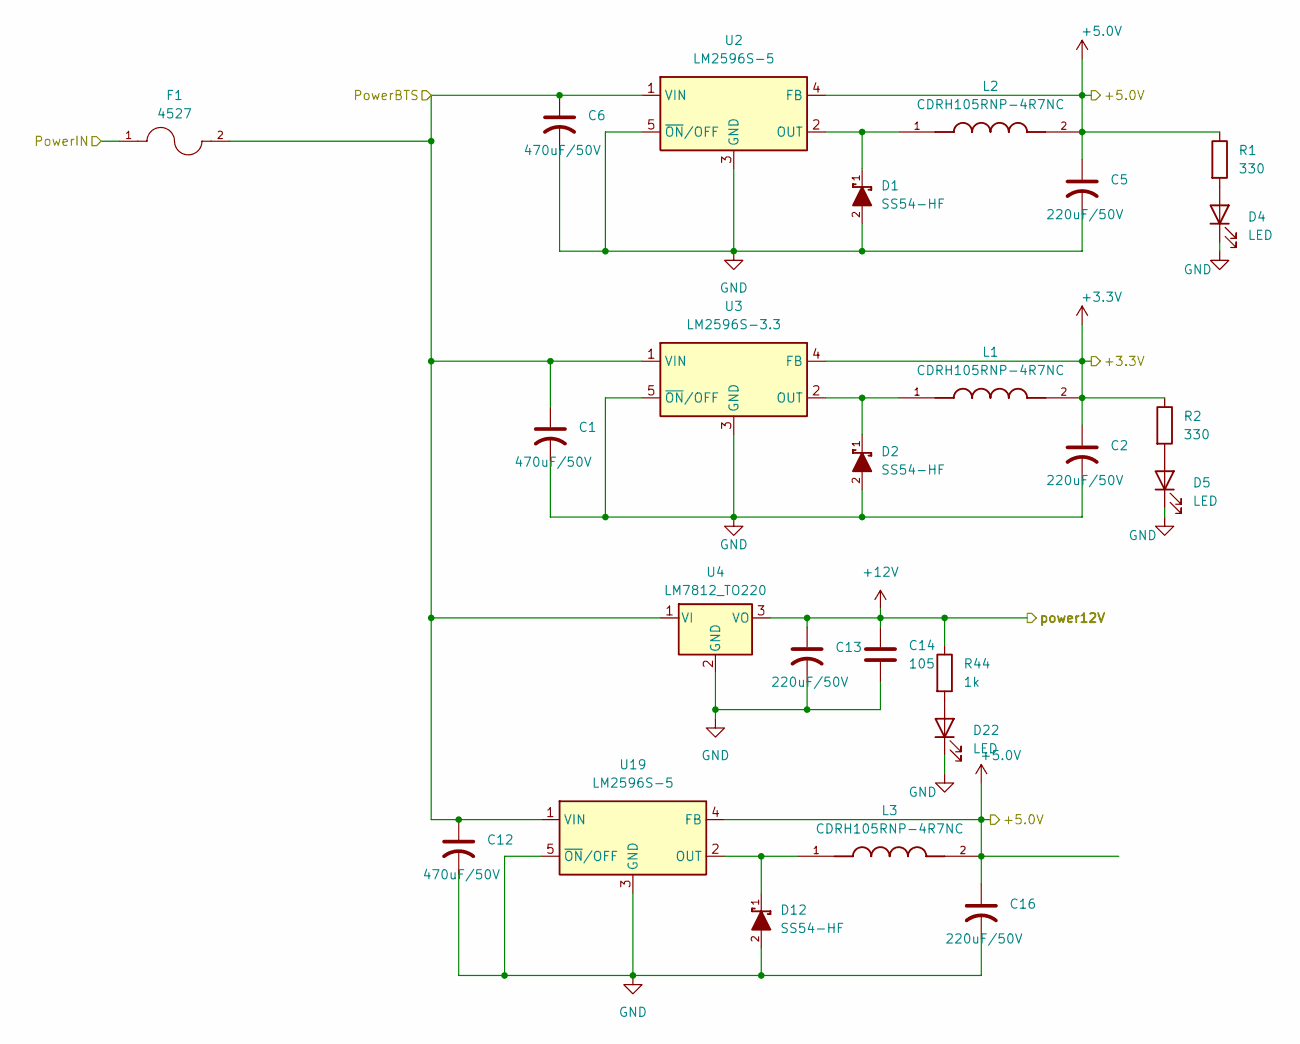
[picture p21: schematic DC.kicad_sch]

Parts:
C1, C6, C12: 470uF/50V; CP_Elec_10x10.5
C2, C5, C13, C16: 220uF/50V; CP_Elec_10x10.5
C14: 105; C_0805_2012Metric
D1, D2, D12: SS54-HF; DIOM5025X220N; MOUSER_PART_NUMBER 750-SS54-HF
D4, D5, D22: LED; LED_0805_2012Metric
F1: 4527; FUSE_4527
L1, L2, L3: CDRH105RNP-4R7NC; IND_CDRH105RNP-4R7NC; PARTREV 23-Oct-2017
R1, R2: 330; R_0805_2012Metric_Pad1.20x1.40mm_HandSolder
R44: 1k; R_0805_2012Metric_Pad1.20x1.40mm_HandSolder
U2, U19: LM2596S-5; TO-263-5_TabPin3
U3: LM2596S-3.3; TO-263-5_TabPin3
U4: LM7812_TO220; TO-220-3_Vertical

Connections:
+3.3V: C2.1, L1.2, R2.1, U3.4 (FB); also elsewhere on the board
+5.0V: C5.1, C16.1, L2.2, L3.2, R1.1, U2.4 (FB), U19.4 (FB); also elsewhere on the board
+12V: C13.1, C14.1, R44.1, U4.3 (VO); also elsewhere on the board
/DC-DC/PowerBTS: C1.1, C6.1, C12.1, F1.2, U2.1 (VIN), U3.1 (VIN), U4.1 (VI), U19.1 (VIN); also elsewhere on the board
/DC-DC/PowerIN: F1.1; also elsewhere on the board
GND: C1.2, C2.2, C5.2, C6.2, C12.2, C13.2, C14.2, C16.2, D1.2, D2.2, D4.1 (K), D5.1 (K), D12.2, D22.1 (K), U2.3 (GND), U2.5 (~ON/OFF), U3.3 (GND), U3.5 (~ON/OFF), U4.2 (GND), U19.3 (GND), U19.5 (~ON/OFF); also elsewhere on the board
unnamed: D4.2 (A), R1.2
unnamed: D5.2 (A), R2.2
unnamed: D22.2 (A), R44.2
unnamed: D1.1, L2.1, U2.2 (OUT)
unnamed: D2.1, L1.1, U3.2 (OUT)
unnamed: D12.1, L3.1, U19.2 (OUT)

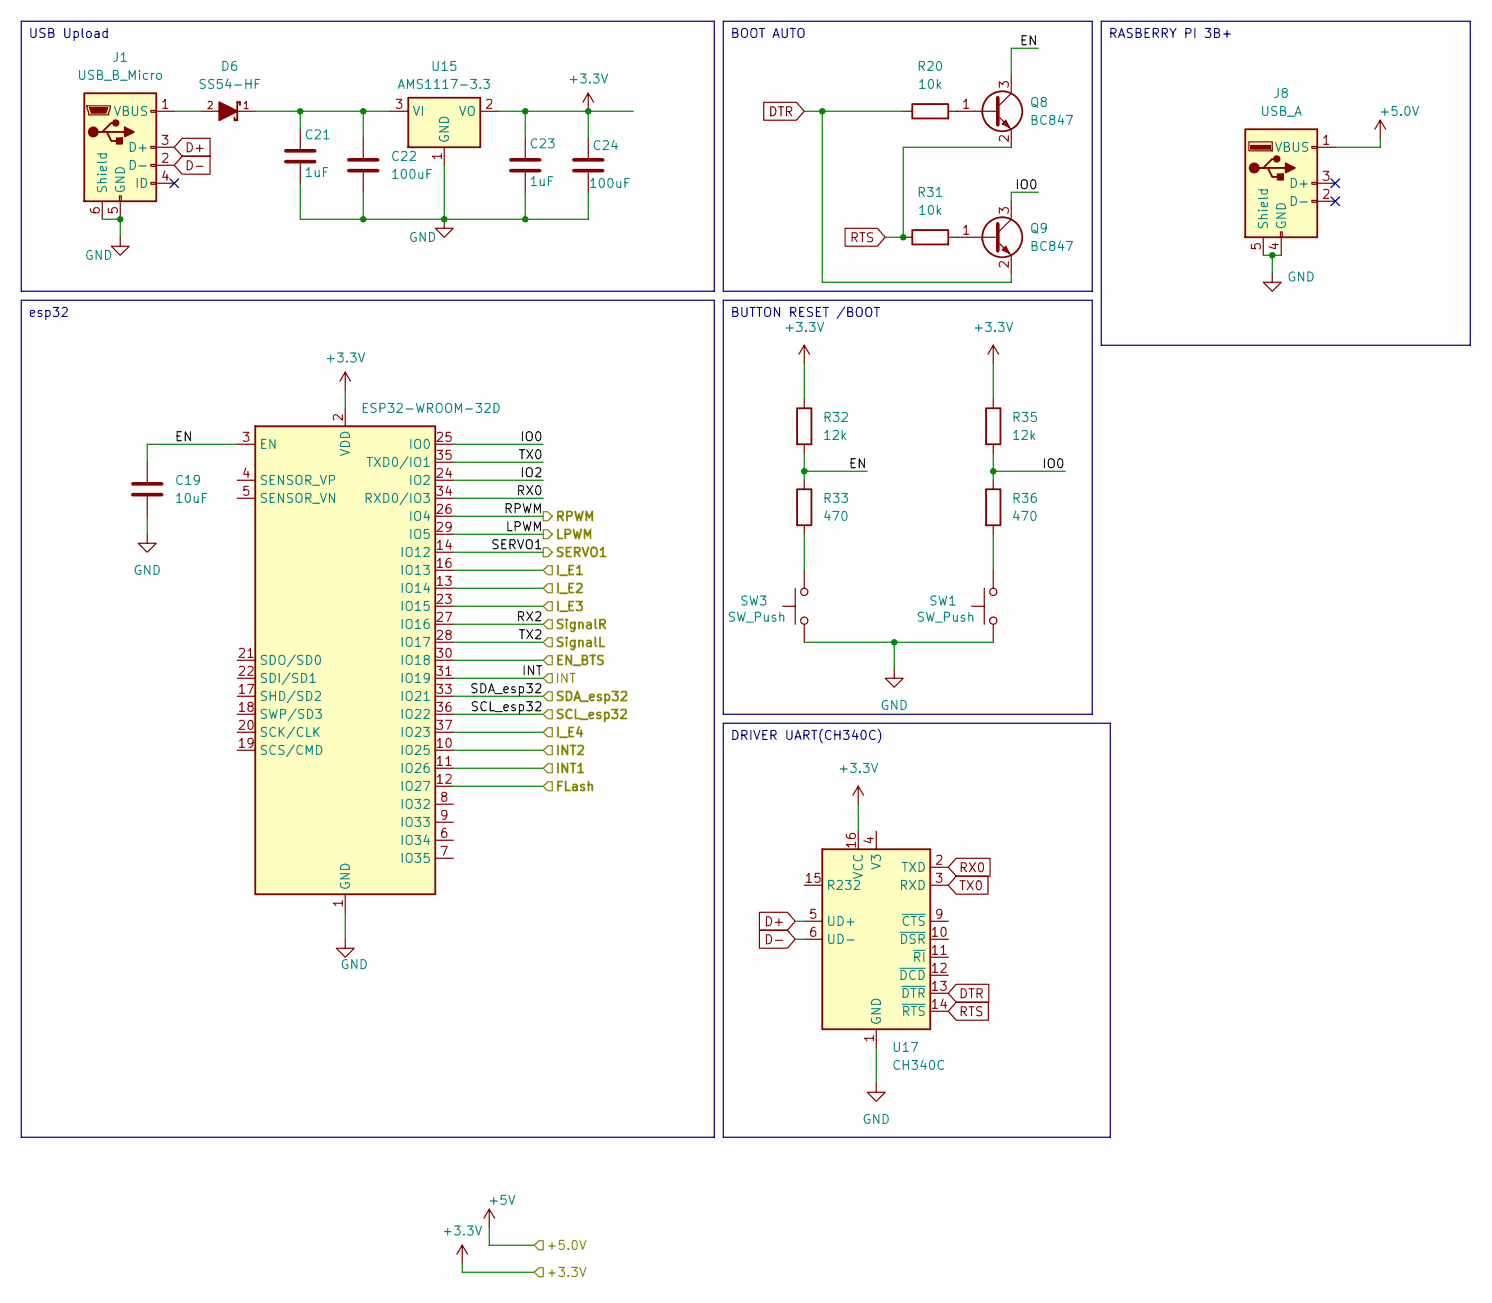
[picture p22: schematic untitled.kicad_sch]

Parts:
C19: 10uF; C_0805_2012Metric_Pad1.18x1.45mm_HandSolder
C21, C23: 1uF; C_0805_2012Metric_Pad1.18x1.45mm_HandSolder
C22, C24: 100uF; CP_Elec_6.3x5.4
D6: SS54-HF; DIOM5025X220N; MOUSER_PART_NUMBER 750-SS54-HF
J1: USB_B_Micro; USB_Micro-B_Molex-105017-0001
J8: USB_A; USB_A_Stewart_SS-52100-001_Horizontal
Q8, Q9: BC847; SOT-23
R20, R31: 10k; R_0805_2012Metric_Pad1.20x1.40mm_HandSolder
R32, R35: 12k; R_0805_2012Metric_Pad1.20x1.40mm_HandSolder
R33, R36: 470; R_0805_2012Metric_Pad1.20x1.40mm_HandSolder
SW1, SW3: SW_Push; SW_Push_1P1T_NO_E-Switch_TL3301NxxxxxG
U14: ESP32-WROOM-32D
U15: AMS1117-3.3; SOT-223-3_TabPin2
U17: CH340C; SOIC-16_3.9x9.9mm_P1.27mm

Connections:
+3.3V: C23.1, C24.1, R32.1, R35.1, U14.2 (VDD), U15.2 (VO), U17.16 (VCC); also elsewhere on the board
+5.0V: J8.1 (VBUS); also elsewhere on the board
/Microcontroler/EN: C19.1, Q8.3 (C), R32.2, R33.1, U14.3 (EN)
/Microcontroler/EN_BTS: U14.30 (IO18); also elsewhere on the board
/Microcontroler/FLash: U14.12 (IO27); also elsewhere on the board
/Microcontroler/INT: U14.31 (IO19); also elsewhere on the board
/Microcontroler/INT1: U14.11 (IO26); also elsewhere on the board
/Microcontroler/INT2: U14.10 (IO25); also elsewhere on the board
/Microcontroler/IO0: Q9.3 (C), R35.2, R36.1, U14.25 (IO0)
/Microcontroler/IO2: U14.24 (IO2)
/Microcontroler/LPWM: U14.29 (IO5); also elsewhere on the board
/Microcontroler/RPWM: U14.26 (IO4); also elsewhere on the board
/Microcontroler/RX2: U14.27 (IO16); also elsewhere on the board
/Microcontroler/SCL_esp32: U14.36 (IO22); also elsewhere on the board
/Microcontroler/SDA_esp32: U14.33 (IO21); also elsewhere on the board
/Microcontroler/SERVO1: U14.14 (IO12); also elsewhere on the board
/Microcontroler/TX2: U14.28 (IO17); also elsewhere on the board
/Ngoại vi/In3V1: U14.16 (IO13); also elsewhere on the board
/Ngoại vi/In3V2: U14.13 (IO14); also elsewhere on the board
/Ngoại vi/In3V3: U14.23 (IO15); also elsewhere on the board
/Ngoại vi/In3V4: U14.37 (IO23); also elsewhere on the board
D+: J1.3 (D+), U17.5 (UD+)
D-: J1.2 (D-), U17.6 (UD-)
DTR: Q9.2 (E), R20.1, U17.13 (~DTR)
GND: C19.2, C21.2, C22.2, C23.2, C24.2, J1.5 (GND), J1.6 (Shield), J8.4 (GND), J8.5 (Shield), SW1.1, SW3.1, U14.1 (GND), U14.15 (GND), U14.38 (GND), U14.39 (GND), U15.1 (GND), U17.1 (GND); also elsewhere on the board
unnamed: D6.2, J1.1 (VBUS)
unnamed: Q8.1 (B), R20.2
unnamed: Q9.1 (B), R31.2
unnamed: R33.2, SW3.2
unnamed: R36.2, SW1.2
unnamed: C21.1, C22.1, D6.1, U15.3 (VI)
RTS: Q8.2 (E), R31.1, U17.14 (~RTS)
RX0: U14.34 (RXD0/IO3), U17.2 (TXD)
TX0: U14.35 (TXD0/IO1), U17.3 (RXD)

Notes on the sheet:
RASBERRY PI 3B+
DRIVER UART(CH340C)
BOOT AUTO
BUTTON RESET /BOOT
USB Upload
esp32

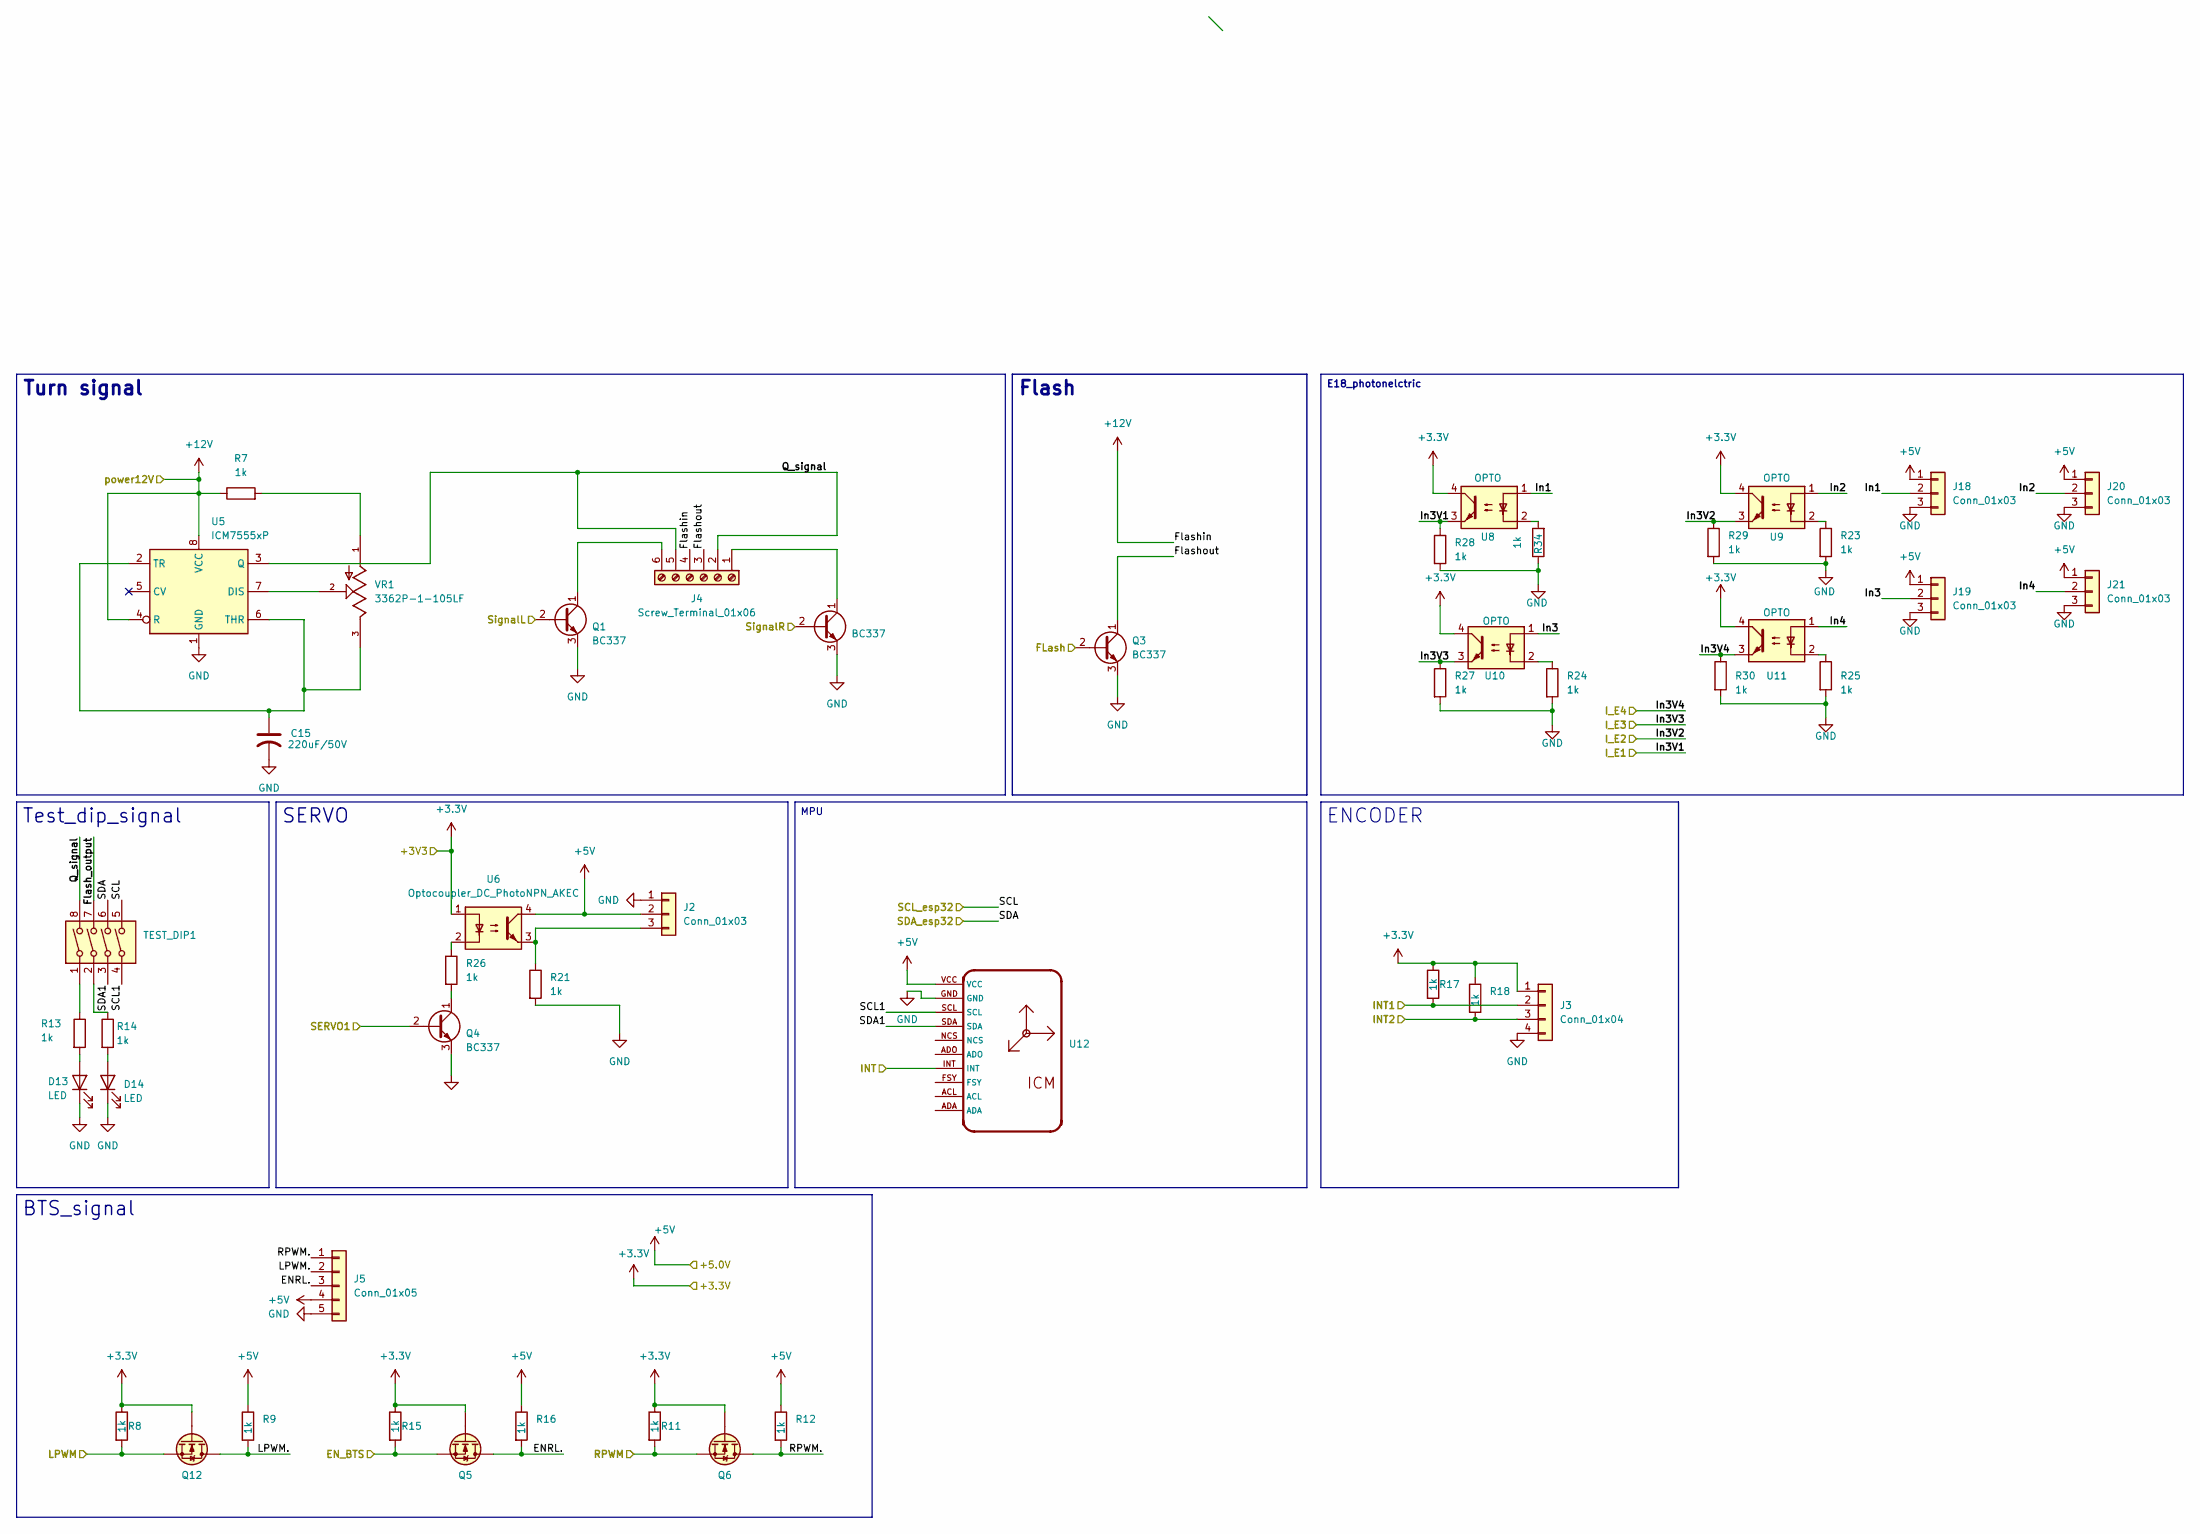
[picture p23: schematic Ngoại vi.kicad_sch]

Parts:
C15: 220uF/50V; CP_Elec_10x10.5
D13, D14: LED; LED_0805_2012Metric
J2, J18, J19, J20, J21: Conn_01x03; PinHeader_1x03_P2.54mm_Vertical
J3: Conn_01x04; JST_B4B-XH-A_LF__SN_
J4: Screw_Terminal_01x06; PhoenixContact_MSTBA_2,5_6-G-5,08_1x06_P5.08mm_Horizontal
J5: Conn_01x05; PinHeader_1x05_P2.54mm_Vertical
Q1, Q2, Q3, Q4: BC337; TO-92_Inline
Q5, Q6, Q12: N_Mosfet; SOT-23-3
R7, R8, R9, R11, R12, R13, R14, R15, R16, R17, R18, R21, R23, R24, R25, R26, R27, R28, R29, R30, R34: 1k; R_0805_2012Metric_Pad1.20x1.40mm_HandSolder
TEST_DIP1: SW_DIP_x04; SW_DIP_SPSTx04_Slide_9.78x12.34mm_W7.62mm_P2.54mm
U5: ICM7555xP; DIP-8_W7.62mm
U6: Optocoupler_DC_PhotoNPN_AKEC; OptoIsolation-EL357N-G
U8, U9, U10, U11: OPTO; OptoIsolation-EL357N-G
U12: ICM
VR1: 3362P-1-105LF; TRIM_3362P-1-105LF; PARTREV 08/26/10

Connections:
+3.3V: J3.1, Q5.1 (G), Q6.1 (G), Q12.1 (G), R8.1, R11.1, R15.1, R17.1, R18.1, U6.1, U8.4, U9.4, U10.4, U11.4; also elsewhere on the board
+5.0V: J2.2, J5.4, J18.1, J19.1, J20.1, J21.1, R9.1, R12.1, R16.1, U6.4, U12.VCC; also elsewhere on the board
+12V: J4.4, R7.1, U5.4 (R), U5.8 (VCC); also elsewhere on the board
/Microcontroler/EN_BTS: Q5.2 (S), R15.2; also elsewhere on the board
/Microcontroler/FLash: Q3.2 (B); also elsewhere on the board
/Microcontroler/INT: U12.INT; also elsewhere on the board
/Microcontroler/INT1: J3.2, R17.2; also elsewhere on the board
/Microcontroler/INT2: J3.3, R18.2; also elsewhere on the board
/Microcontroler/LPWM: Q12.2 (S), R8.2; also elsewhere on the board
/Microcontroler/RPWM: Q6.2 (S), R11.2; also elsewhere on the board
/Microcontroler/RX2: Q2.2 (B); also elsewhere on the board
/Microcontroler/SCL_esp32: TEST_DIP1.5; also elsewhere on the board
/Microcontroler/SDA_esp32: TEST_DIP1.6; also elsewhere on the board
/Microcontroler/SERVO1: Q4.2 (B); also elsewhere on the board
/Microcontroler/TX2: Q1.2 (B); also elsewhere on the board
/Ngoại vi/ENRL.: J5.3, Q5.3 (D), R16.2
/Ngoại vi/Flash_output: TEST_DIP1.7
/Ngoại vi/Flashout: J4.3, Q3.1 (C)
/Ngoại vi/In1: J18.2, U8.1
/Ngoại vi/In2: J20.2, U9.1
/Ngoại vi/In3: J19.2, U10.1
/Ngoại vi/In3V1: R28.1, U8.3; also elsewhere on the board
/Ngoại vi/In3V2: R29.1, U9.3; also elsewhere on the board
/Ngoại vi/In3V3: R27.1, U10.3; also elsewhere on the board
/Ngoại vi/In3V4: R30.1, U11.3; also elsewhere on the board
/Ngoại vi/In4: J21.2, U11.1
/Ngoại vi/LPWM.: J5.2, Q12.3 (D), R9.2
/Ngoại vi/Q_signal: J4.2, J4.5, TEST_DIP1.8, U5.3 (Q)
/Ngoại vi/RPWM.: J5.1, Q6.3 (D), R12.2
/Ngoại vi/SCL1: TEST_DIP1.4, U12.SCL
/Ngoại vi/SDA1: TEST_DIP1.3, U12.SDA
GND: C15.2, D13.1 (K), D14.1 (K), J2.1, J3.4, J5.5, J18.3, J19.3, J20.3, J21.3, Q1.3 (E), Q2.3 (E), Q3.3 (E), Q4.3 (E), R21.2, R23.2, R24.2, R25.2, R27.2, R28.2, R29.2, R30.2, R34.1, U5.1 (GND), U12.GND; also elsewhere on the board
unnamed: D13.2 (A), R13.2
unnamed: D14.2 (A), R14.2
unnamed: J2.3, R21.1, U6.3
unnamed: J4.1, Q2.1 (C)
unnamed: J4.6, Q1.1 (C)
unnamed: Q4.1 (C), R26.2
unnamed: R7.2, VR1.1
unnamed: R13.1, TEST_DIP1.1
unnamed: R14.1, TEST_DIP1.2
unnamed: R23.1, U9.2
unnamed: R24.1, U10.2
unnamed: R25.1, U11.2
unnamed: R26.1, U6.2
unnamed: R34.2, U8.2
unnamed: U5.7 (DIS), VR1.2
unnamed: C15.1, U5.2 (TR), U5.6 (THR), VR1.3

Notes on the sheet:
Test_dip_signal
Flash
E18_photonelctric
BTS_signal
Turn signal
SERVO
MPU
ENCODER

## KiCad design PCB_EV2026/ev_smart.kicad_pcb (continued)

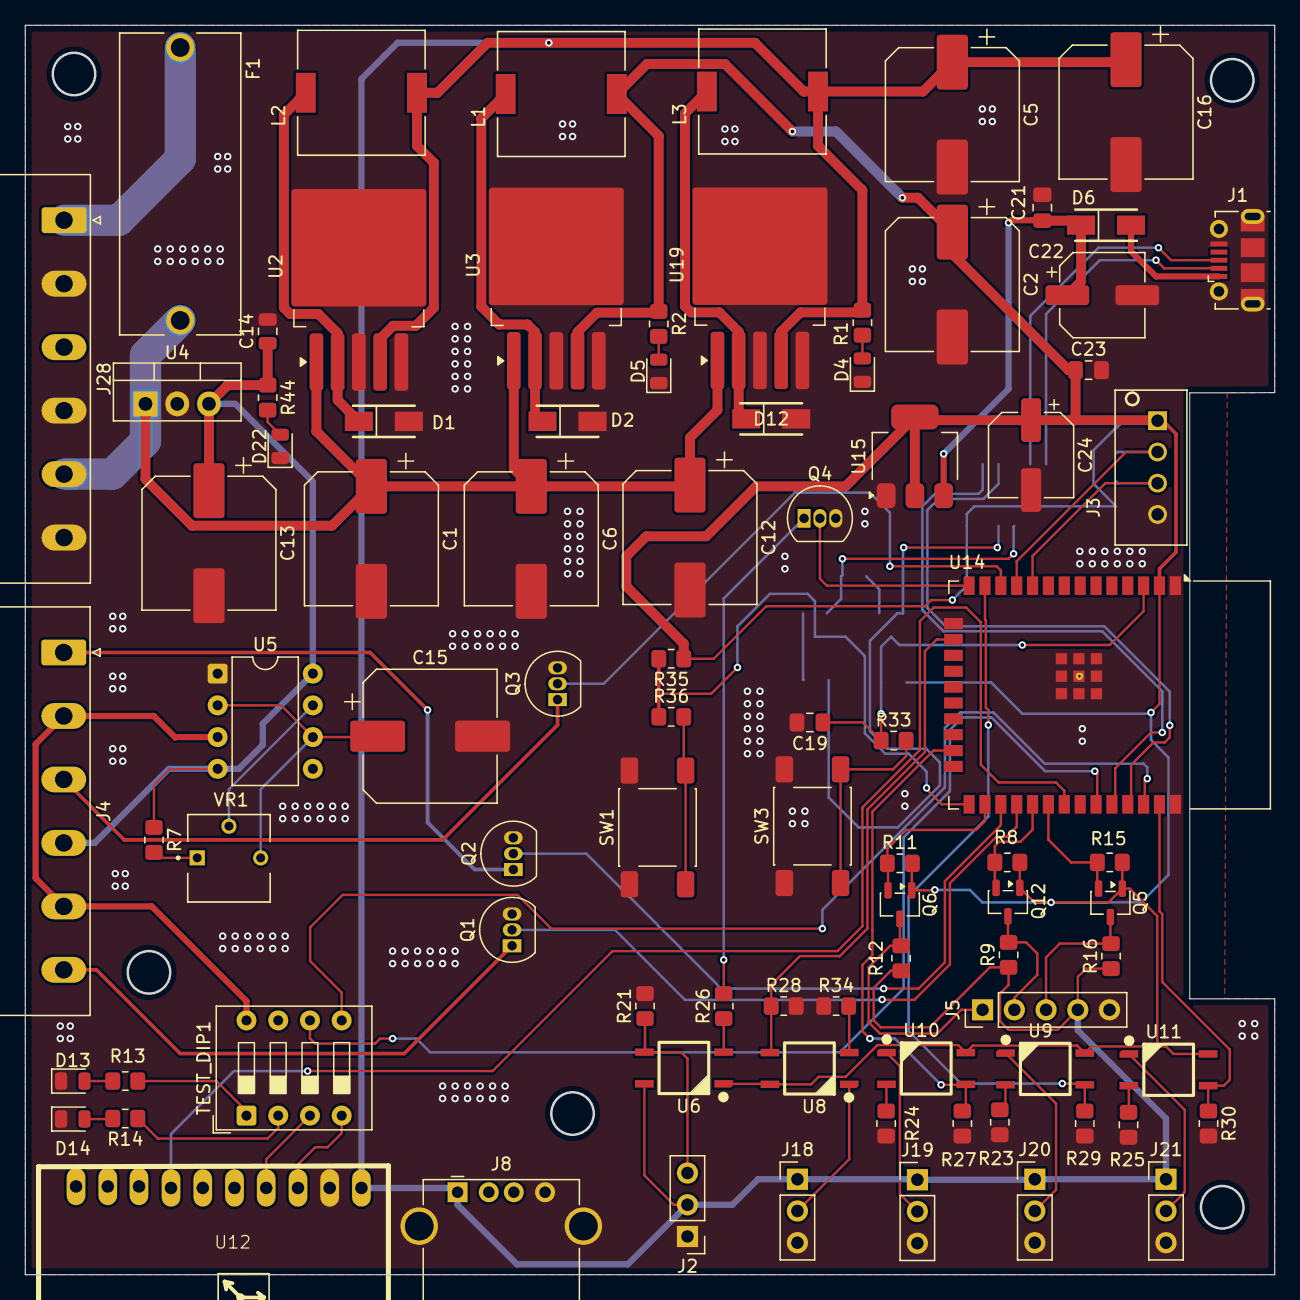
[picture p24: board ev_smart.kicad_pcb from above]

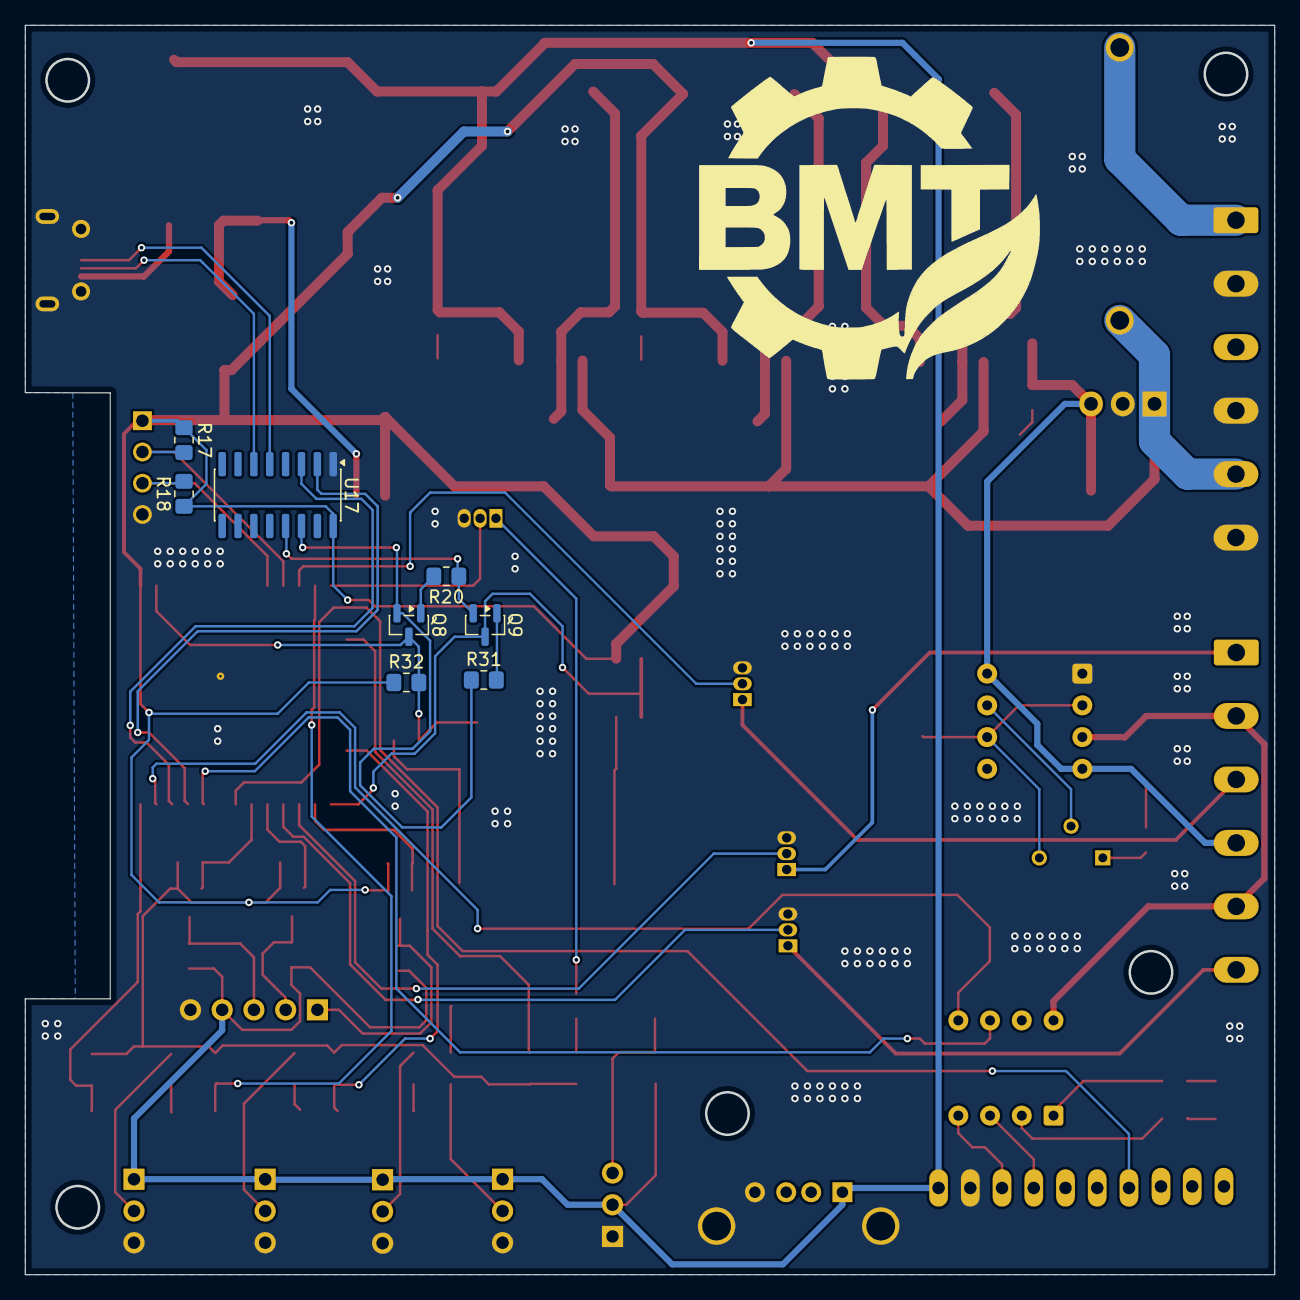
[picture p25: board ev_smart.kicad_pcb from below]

Board: 2 copper layers, 100.0 x 100.0 mm, 95 parts (8 on the bottom side), 69 nets.

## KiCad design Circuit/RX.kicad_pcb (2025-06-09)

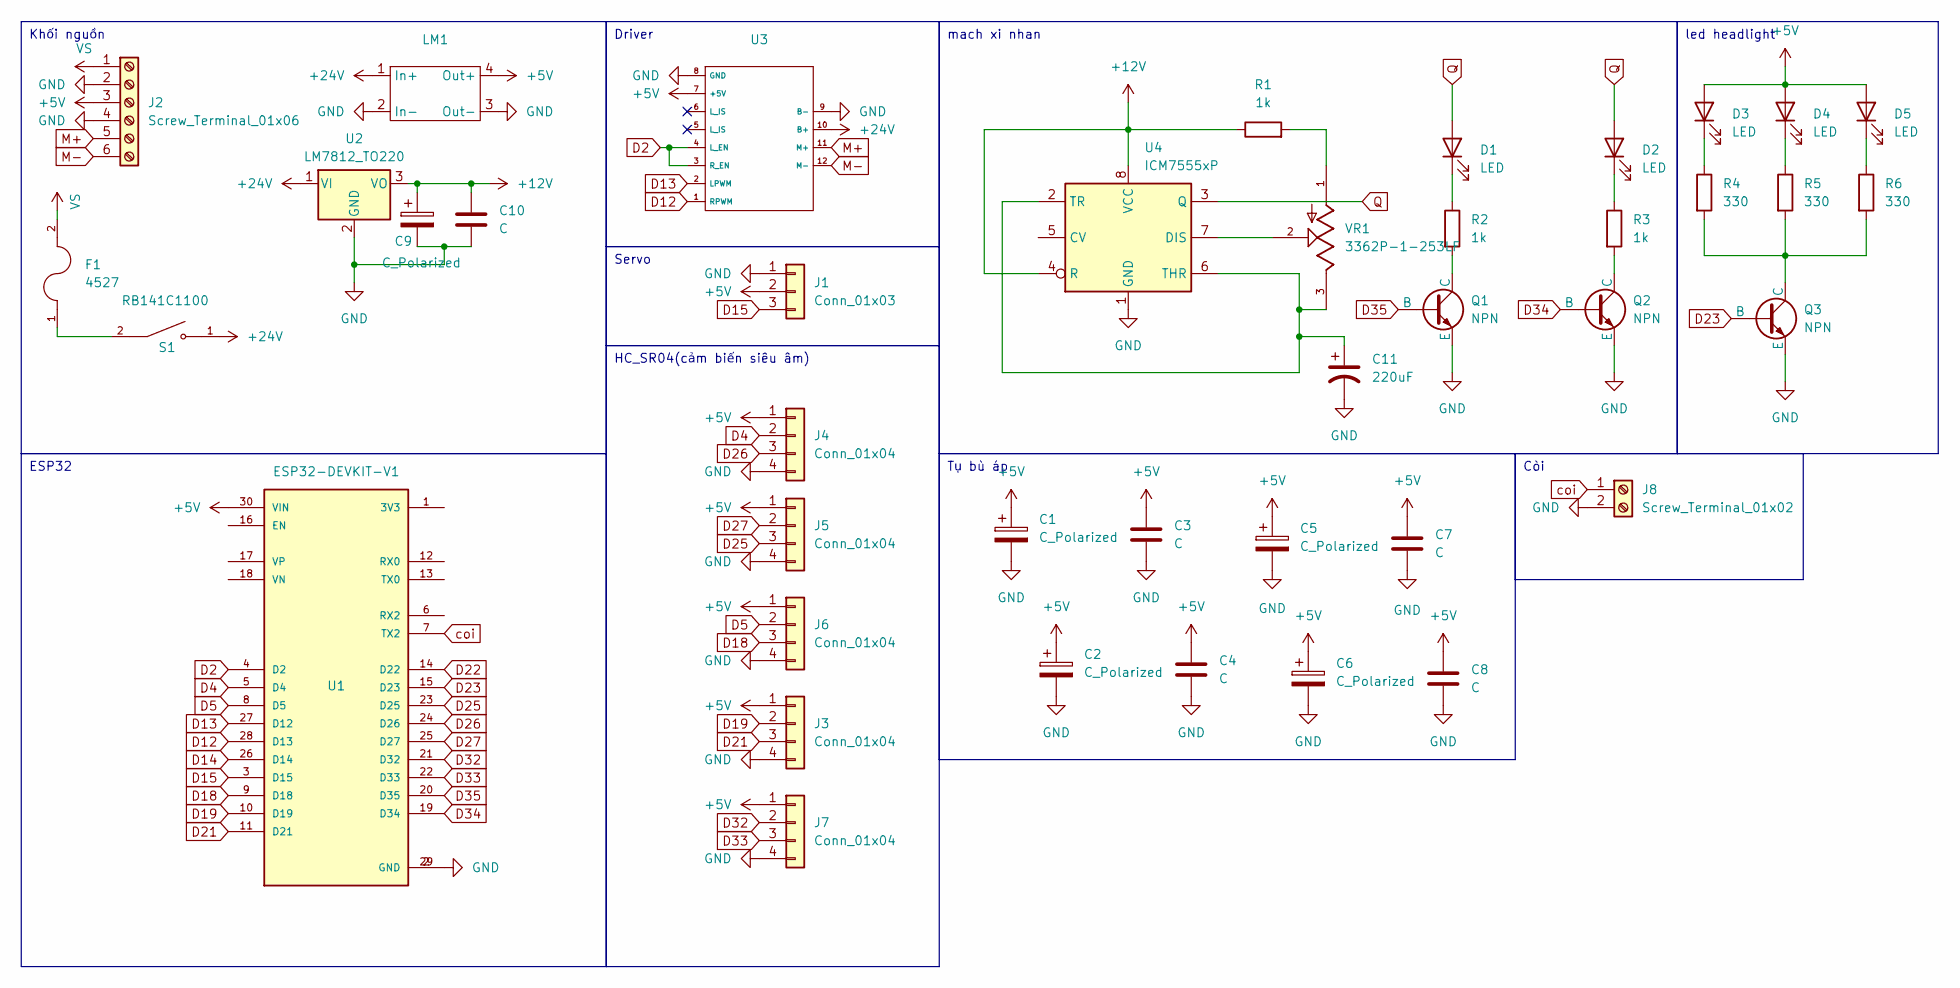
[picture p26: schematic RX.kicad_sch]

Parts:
C1, C2, C5, C6, C9: C_Polarized; CP_Radial_D4.0mm_P2.00mm
C3, C4, C7, C8, C10: C; C_Disc_D5.0mm_W2.5mm_P2.50mm
C11: 220uF; CP_Radial_D10.0mm_P3.80mm
D1, D2, D3, D4, D5: LED; LED_D4.0mm
F1: 4527; FUSE_4527; PARTREV B
J1: Conn_01x03; TerminalBlock_Phoenix_MKDS-1,5-3-5.08_1x03_P5.08mm_Horizont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
J2: Screw_Terminal_01x06; TerminalBlock_Phoenix_MKDS-1,5-6-5.08_1x06_P5.08mm_Horizont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
J3, J4, J5, J6, J7: Conn_01x04; PinHeader_1x04_P2.54mm_Vertical
J8: Screw_Terminal_01x02; TerminalBlock_Phoenix_MKDS-1,5-2-5.08_1x02_P5.08mm_Horizont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
LM1: Lm2596
Q1, Q2, Q3: NPN; TO-92L_Inline_Wide
R1, R2, R3: 1k; R_Axial_DIN0204_L3.6mm_D1.6mm_P7.62mm_Horizontal
R4, R5, R6: 330; R_Axial_DIN0204_L3.6mm_D1.6mm_P7.62mm_Horizontal
S1: RB141C1100; SW_POWER; PARTREV C
U1: ESP32-DEVKIT-V1; MODULE_ESP32_DEVKIT_V1; PARTREV N/A
U2: LM7812_TO220; TO-220-3_Vertical
U3: BTS
U4: ICM7555xP; DIP-8_W7.62mm
VR1: 3362P-1-253LF; TRIM_3362P-1-253LF; PARTREV 08/26/10

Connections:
+5V: C1.1, C2.1, C3.1, C4.1, C5.1, C6.1, C7.1, C8.1, D3.2 (A), D4.2 (A), D5.2 (A), J1.2, J2.3, J3.1, J4.1, J5.1, J6.1, J7.1, LM1.4 (Out+), U1.30 (VIN), U3.7 (+5V)
+12V: C9.1, C10.1, R1.1, U2.3 (VO), U4.4 (R), U4.8 (VCC)
+24V: LM1.1 (In+), S1.1, U2.1 (VI), U3.10 (B+)
D2: U1.4 (D2), U3.3 (R_EN), U3.4 (L_EN)
D4: J4.2, U1.5 (D4)
D5: J6.2, U1.8 (D5)
D12: U1.28 (D13), U3.1 (RPWM)
D13: U1.27 (D12), U3.2 (LPWM)
D14: U1.26 (D14)
D15: J1.3, U1.3 (D15)
D18: J6.3, U1.9 (D18)
D19: J3.2, U1.10 (D19)
D21: J3.3, U1.11 (D21)
D22: U1.14 (D22)
D23: Q3.2 (B), U1.15 (D23)
D25: J5.3, U1.23 (D25)
D26: J4.3, U1.24 (D26)
D27: J5.2, U1.25 (D27)
D32: J7.2, U1.21 (D32)
D33: J7.3, U1.22 (D33)
D34: Q2.2 (B), U1.19 (D34)
D35: Q1.2 (B), U1.20 (D35)
GND: C1.2, C2.2, C3.2, C4.2, C5.2, C6.2, C7.2, C8.2, C9.2, C10.2, C11.2, J1.1, J2.2, J2.4, J3.4, J4.4, J5.4, J6.4, J7.4, J8.2, LM1.2 (In-), LM1.3 (Out-), Q1.3 (E), Q2.3 (E), Q3.3 (E), U1.2 (GND), U1.29 (GND), U2.2 (GND), U3.8 (GND), U3.9 (B-), U4.1 (GND)
M+: J2.5, U3.11 (M+)
M-: J2.6, U3.12 (M-)
unnamed: D1.1 (K), R2.1
unnamed: D2.1 (K), R3.1
unnamed: D3.1 (K), R4.1
unnamed: D4.1 (K), R5.1
unnamed: D5.1 (K), R6.1
unnamed: F1.1, S1.2
unnamed: Q1.1 (C), R2.2
unnamed: Q2.1 (C), R3.2
unnamed: Q3.1 (C), R4.2, R5.2, R6.2
unnamed: R1.2, VR1.1
unnamed: U4.7 (DIS), VR1.2
unnamed: C11.1, U4.2 (TR), U4.6 (THR), VR1.3
Q: D1.2 (A), D2.2 (A), U4.3 (Q)
VS: F1.2, J2.1
coi: J8.1, U1.7 (TX2)

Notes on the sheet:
Còi
mach xi nhan
Tụ bù áp
Khối nguồn
HC_SR04(cảm biến siêu âm)
led headlight
Servo
Driver
ESP32


Board: 2 copper layers, 63.9 x 167.6 mm, 41 parts (0 on the bottom side), 38 nets.

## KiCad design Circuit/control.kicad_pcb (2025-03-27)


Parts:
C1, C3, C4, C7: C_Polarized; CP_Radial_D4.0mm_P2.00mm
C2, C5, C6, C8: C; C_Disc_D5.0mm_W2.5mm_P2.50mm
J1: Barrel_Jack_Switch_Pin3Ring; BarrelJack_Horizontal
LM1: Lm2596
RV1: R_Potentiometer; Potentiometer_Piher_PC-16_Single_Horizontal
S1: TL2230OAF140; SW_6 pins 8.5×8.5MM; PARTREV E
SW1, SW2, SW3, SW4, SW5, SW6: SW_Push; SW_PUSH_6mm_H9.5mm
U1: ESP32-DEVKIT-V1; MODULE_ESP32_DEVKIT_V1; PARTREV N/A
U2, U3: COM-09032; joystick; PARTREV N/A

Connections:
+3.3V: C3.1, C4.1, C5.1, C6.1, C7.1, C8.1, RV1.1, U1.1 (3V3), U2.H1 (H+), U2.V1 (V+), U3.H1 (H+), U3.V1 (V+)
+5V: C1.1, C2.1, LM1.4 (Out+), U1.30 (VIN)
+12V: LM1.1 (In+), S1.3, S1.6
B1: SW1.2, U1.4 (D2)
B2: SW2.2, U1.5 (D4)
B3: SW3.2, U1.8 (D5)
B4: SW4.2, U1.27 (D12)
B5: SW5.2, U1.28 (D13)
B6: SW6.2, U1.26 (D14)
GND: C1.2, C2.2, C3.2, C4.2, C5.2, C6.2, C7.2, C8.2, J1.2, J1.3, LM1.2 (In-), LM1.3 (Out-), RV1.3, SW1.1, SW2.1, SW3.1, SW4.1, SW5.1, SW6.1, U1.2 (GND), U1.29 (GND), U2.B2A (SEL-), U2.H3 (H-), U2.S1 (SHIELD), U2.S2 (SHIELD), U2.S3 (SHIELD), U2.S4 (SHIELD), U2.V3 (V-), U3.B2A (SEL-), U3.H3 (H-), U3.S1 (SHIELD), U3.S2 (SHIELD), U3.S3 (SHIELD), U3.S4 (SHIELD), U3.V3 (V-)
JSW1: U1.3 (D15), U2.B1A (SEL+)
JSW2: U1.9 (D18), U3.B1A (SEL+)
unnamed: RV1.2, U1.24 (D26)
VLx2: U1.19 (D34), U3.H2 (H)
VLy2: U1.22 (D33), U3.V2 (V)
VRx1: U1.21 (D32), U2.H2 (H)
VRy1: U1.20 (D35), U2.V2 (V)
Vin1: J1.1, S1.2, S1.5

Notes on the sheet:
NÚT NHẤN
ESP32
Joystick
NGUON
TỤ BÙ ÁP


Board: 2 copper layers, 117.7 x 76.5 mm, 21 parts (0 on the bottom side), 18 nets.

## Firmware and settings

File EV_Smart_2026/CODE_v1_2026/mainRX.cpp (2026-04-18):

#include <Arduino.h>
#include <Wire.h>
#include <esp_now.h>
#include <WiFi.h>
#include <esp_wifi.h>

#define RPWM_CHANNEL 0
#define LPWM_CHANNEL 1
#define SERVO_CHANNEL 2

// ======== Pins ========
const int steeringPin = 12;
const int RPWM = 4;
const int LPWM = 5;
const int EN_PIN = 18;
const int LED_F = 27;
const int LED_TURN_R = 16;
const int LED_TURN_L = 17;

const int MotorPWMFreq = 1000;
const int ServoPWMFreq = 50;
const int PWMResolution = 8;

#define SIGNAL_TIMEOUT 1000
unsigned long lastRecvTime = 0;

// ======== Data Packet (đồng bộ với TX) ========
typedef struct {
  uint8_t header;
  uint8_t ly, rx, ry, pot;
  bool b1, b2, b3, b4, b5, b6, b7, b8, b9, b10, b11, b12, js1, js2;
  uint8_t footer;
} DataPacket;

DataPacket receiverData;

// ======== Motor & Servo ========
void goAhead(int speed) {
  digitalWrite(EN_PIN, HIGH);
  ledcWrite(RPWM_CHANNEL, 0);
  ledcWrite(LPWM_CHANNEL, speed);
}

void goBack(int speed) {
  digitalWrite(EN_PIN, HIGH);
  ledcWrite(RPWM_CHANNEL, speed);
  ledcWrite(LPWM_CHANNEL, 0);
}

void stopMotor() {
  digitalWrite(EN_PIN, LOW);
  ledcWrite(RPWM_CHANNEL, 0);
  ledcWrite(LPWM_CHANNEL, 0);
}

void brakeMotor() {
  digitalWrite(EN_PIN, HIGH);
  ledcWrite(RPWM_CHANNEL, 0);
  ledcWrite(LPWM_CHANNEL, 0);
}

void setServoAngle(int angle) {
  int duty = map(angle, 0, 180, 1638, 8192);
  ledcWrite(SERVO_CHANNEL, duty);

  int steering = map(receiverData.rx, 0, 254, 0, 206);
  if (steering > 100) {
    digitalWrite(LED_TURN_R, HIGH);
    digitalWrite(LED_TURN_L, LOW);
  } else if (steering < 60) {
    digitalWrite(LED_TURN_R, LOW);
    digitalWrite(LED_TURN_L, HIGH);
  } else {
    digitalWrite(LED_TURN_R, LOW);
    digitalWrite(LED_TURN_L, LOW);
  }
}

void controlMotor() {
  int motorSpeed = map(receiverData.ly, 0, 254, -255, 255);
  int pwmSpeed   = map(receiverData.pot, 0, 254, 0, 255);

  if (motorSpeed > 50)       goAhead(pwmSpeed);
  else if (motorSpeed < -50) goBack(pwmSpeed > 130 ? pwmSpeed - 30 : pwmSpeed);
  else                       stopMotor();
}

void setUpPinModes() {
  pinMode(EN_PIN, OUTPUT);
  pinMode(LED_F, OUTPUT);
  pinMode(LED_TURN_L, OUTPUT);
  pinMode(LED_TURN_R, OUTPUT);
  pinMode(RPWM, OUTPUT);
  pinMode(LPWM, OUTPUT);
  digitalWrite(LED_F, LOW);

  ledcSetup(RPWM_CHANNEL, MotorPWMFreq, PWMResolution);
  ledcAttachPin(RPWM, RPWM_CHANNEL);

  ledcSetup(LPWM_CHANNEL, MotorPWMFreq, PWMResolution);
  ledcAttachPin(LPWM, LPWM_CHANNEL);

  ledcSetup(SERVO_CHANNEL, ServoPWMFreq, 16);
  ledcAttachPin(steeringPin, SERVO_CHANNEL);

  setServoAngle(90);
}

// ======== ESP-NOW Callback ========
void OnDataRecv(const uint8_t *mac_addr, const uint8_t *incomingData, int len) {
  Serial.print("Received! len=");
  Serial.print(len);
  Serial.print(" expected=");
  Serial.println(sizeof(DataPacket));

  if (len != sizeof(DataPacket)) return;
  memcpy(&receiverData, incomingData, sizeof(receiverData));
  if (receiverData.header != 0x4E || receiverData.footer != 0x42) return;

  lastRecvTime = millis();
  Serial.println("Valid packet!");

  // Lái + ga
  int steering  = map(receiverData.rx, 0, 254, 0, 206);
  int ssteering = constrain(steering, 60, 130);
  setServoAngle(ssteering);
  controlMotor();

  // js1: tiến full + bật đèn pha
  if (receiverData.js1) {
    digitalWrite(LED_F, HIGH);
    goAhead(255);
  }

  // js2: phanh + trả lái giữa
  if (receiverData.js2) {
    brakeMotor();
    setServoAngle(90);
  }
}

// ======== Setup & Loop ========
void setup() {
  Serial.begin(115200);
  setUpPinModes();

  WiFi.mode(WIFI_STA);
  esp_wifi_set_channel(6, WIFI_SECOND_CHAN_NONE);
  WiFi.setSleep(false);
  esp_wifi_set_max_tx_power(84);
  setCpuFrequencyMhz(240);

  // In MAC để kiểm tra
  Serial.print("Receiver MAC: ");
  Serial.println(WiFi.macAddress());

  if (esp_now_init() != ESP_OK) {
    Serial.println("ESP-NOW init failed");
    return;
  }
  esp_now_set_wake_window(65535);
  esp_now_register_recv_cb(OnDataRecv);

  Serial.println("Receiver ready, waiting for data...");
}

void loop() {
  if (millis() - lastRecvTime > SIGNAL_TIMEOUT) {
    setServoAngle(90);
    stopMotor();
  }
}

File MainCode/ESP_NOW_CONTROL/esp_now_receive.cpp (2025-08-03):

#include <Arduino.h>
#include <Wire.h>
#include <MPU6050.h>
#include <esp_now.h>
#include <WiFi.h>
#include <esp_wifi.h>
#include <PID_v1.h>
#include <math.h>

#define RPWM_CHANNEL 0
#define LPWM_CHANNEL 1
#define SERVO_CHANNEL 2
// ======== MPU6050 ========
MPU6050 mpu;
float angleZ = 0;
float gyroZ_offset = 0;
unsigned long lastMPUTime;

#define FILTER_SIZE 10
float rateZ_buffer[FILTER_SIZE];
int filter_index = 0;

// ======== Yaw PID ========
double yawInput, yawOutput, yawSetpoint = 0;
double yawKp = 3.0, yawKi = 0.2, yawKd = 0.8;
PID yawPID(&yawInput, &yawOutput, &yawSetpoint, yawKp, yawKi, yawKd, DIRECT);

// ======== Pins ========
const int steeringPin = 15;
const int RPWM = 12;
const int LPWM = 13;
const int EN_PIN = 2;
const int LED_F = 23;
const int LED_TURN_R = 16;
const int LED_TURN_L = 17;
int yawDirection = -1; // Đổi -1 hoặc 1 nếu bị ngược

// Chỉ dùng 2 cảm biến: Trái (LEFT) và Phải (RIGHT)
const int trigPins[2] = {4, 27};    // LEFT, RIGHT
const int echoPins[2] = {26, 25};  // LEFT, RIGHT
long duration[2];
float distance[2];

const int MotorPWMFreq = 1000;
const int ServoPWMFreq = 50;
const int PWMResolution = 8;

#define SIGNAL_TIMEOUT 1000
unsigned long lastRecvTime = 0;
bool isSensorMode = false;

// ======== Restore Tracking ========
bool isPathClear = false;
unsigned long sensorClearStart = 0;

// ======== Data Packet ========
typedef struct {
  uint8_t header;
  uint8_t ly, rx, ry, pot;
  bool b1, b2, b3, b4, b5, b6, js1, js2;
  uint8_t footer;
} DataPacket;

DataPacket receiverData;

void setupMPU6050() {
  Wire.begin(33, 32);
  mpu.initialize();
  if (!mpu.testConnection()) {
    Serial.println("MPU6050 không kết nối");
    while (1);
  }
  delay(1000);
  long sum = 0;
  for (int i = 0; i < 1000; i++) {
    int16_t gx, gy, gz;
    mpu.getRotation(&gx, &gy, &gz);
    sum += gz;
    delay(2);
  }
  gyroZ_offset = sum / 1000.0;
  lastMPUTime = millis();
  for (int i = 0; i < FILTER_SIZE; i++) rateZ_buffer[i] = 0;
  yawPID.SetMode(AUTOMATIC);
  yawPID.SetOutputLimits(-40, 40);
}

void updateYaw() {
  if (!isSensorMode) return;
  int16_t gx, gy, gz;
  mpu.getRotation(&gx, &gy, &gz);
  unsigned long now = millis();
  float dt = (now - lastMPUTime) / 1000.0;
  lastMPUTime = now;
  if (dt <= 0 || dt > 1.0) return;

  float rawRateZ = -(gz - gyroZ_offset) / 131.0;
  rateZ_buffer[filter_index] = rawRateZ;
  filter_index = (filter_index + 1) % FILTER_SIZE;

  float filteredRateZ = 0;
  for (int i = 0; i < FILTER_SIZE; i++) filteredRateZ += rateZ_buffer[i];
  filteredRateZ /= FILTER_SIZE;

  angleZ += filteredRateZ * dt;
  angleZ = fmod(angleZ, 360.0);
  if (angleZ < 0) angleZ += 360;
}

void adjustSteeringByYaw() {
  yawInput = angleZ;
  if (yawInput > 180) yawInput -= 360;
  if (yawInput < -180) yawInput += 360;
  yawPID.Compute();
}

void readUltrasonicSensors() {
  // LEFT
digitalWrite(trigPins[0], LOW);
delayMicroseconds(2);
digitalWrite(trigPins[0], HIGH);
delayMicroseconds(10);
digitalWrite(trigPins[0], LOW);
long durationL = pulseIn(echoPins[0], HIGH, 30000);
distance[0] = (durationL == 0) ? -1 : durationL * 0.0343 / 2;

// RIGHT
digitalWrite(trigPins[1], LOW);
delayMicroseconds(2);
digitalWrite(trigPins[1], HIGH);
delayMicroseconds(10);
digitalWrite(trigPins[1], LOW);
long durationR = pulseIn(echoPins[1], HIGH, 30000);
distance[1] = (durationR == 0) ? -1 : durationR * 0.0343 / 2;

}

void goAhead(int speed) {
  digitalWrite(EN_PIN, HIGH);
  ledcWrite(RPWM_CHANNEL, speed);
  ledcWrite(LPWM_CHANNEL, 0);
}

void goBack(int speed) {
  digitalWrite(EN_PIN, HIGH);
  ledcWrite(RPWM_CHANNEL, 0);
  ledcWrite(LPWM_CHANNEL, speed);
}

void stopMotor() {
  digitalWrite(EN_PIN, LOW);
  ledcWrite(RPWM_CHANNEL, 0);
  ledcWrite(LPWM_CHANNEL, 0);
}


void brakeMoter() {
  digitalWrite(EN_PIN, HIGH);
  ledcWrite(RPWM, 0);
  ledcWrite(LPWM, 0);
}

void setServoAngle(int angle) {
  int duty = map(angle, 0, 180, 1638, 8192);
  ledcWrite(SERVO_CHANNEL, duty);

  int steering = map(receiverData.rx, 0, 254, 0, 206);
  if (steering > 100) {
    digitalWrite(LED_TURN_R, HIGH);
    digitalWrite(LED_TURN_L, LOW);
  } else if (steering < 60) {
    digitalWrite(LED_TURN_R, LOW);
    digitalWrite(LED_TURN_L, HIGH);
  } else {
    digitalWrite(LED_TURN_R, LOW);
    digitalWrite(LED_TURN_L, LOW);
  }
}

void controlMotor() {
  int motorSpeed = map(receiverData.ly, 0, 254, -255, 255);
  int pwmSpeed = map(receiverData.pot, 0, 254, 0, 255);
  int steering = map(receiverData.rx , 0, 254, 0, 206);
  int ssteering = constrain(steering, 50, 140);
  if (motorSpeed > 50) goAhead(pwmSpeed);
  else if (motorSpeed < -50) goBack(pwmSpeed > 130 ? pwmSpeed - 30 : pwmSpeed);
  else stopMotor();
}

void setUpPinModes() {
  pinMode(EN_PIN, OUTPUT);
  pinMode(LED_F, OUTPUT);
  pinMode(LED_TURN_L, OUTPUT);
  pinMode(LED_TURN_R, OUTPUT);
  pinMode(RPWM, OUTPUT);
  pinMode(LPWM, OUTPUT);
  digitalWrite(LED_F, LOW);
//   ledcAttach(RPWM, MotorPWMFreq, PWMResolution);
//   ledcAttach(LPWM, MotorPWMFreq, PWMResolution);
//   ledcAttach(steeringPin, ServoPWMFreq, 16);
 // Sử dụng đúng hàm PWM
   // Thiết lập PWM
  ledcSetup(RPWM_CHANNEL, MotorPWMFreq, PWMResolution); // Channel 0
  ledcAttachPin(RPWM, RPWM_CHANNEL);

  ledcSetup(LPWM_CHANNEL, MotorPWMFreq, PWMResolution); // Channel 1
  ledcAttachPin(LPWM, LPWM_CHANNEL);

  ledcSetup(SERVO_CHANNEL, ServoPWMFreq, 16);            // Channel 2
  ledcAttachPin(steeringPin, SERVO_CHANNEL);

  setServoAngle(90);

  for (int i = 0; i < 2; i++) {
    pinMode(trigPins[i], OUTPUT);
    pinMode(echoPins[i], INPUT);
  }
}

void OnDataRecv(const uint8_t *mac_addr, const uint8_t *incomingData, int len) {
  if (len == sizeof(DataPacket)) {
    memcpy(&receiverData, incomingData, sizeof(receiverData));
    if (receiverData.header == 0x4A && receiverData.footer == 0x42) {
      if (!isSensorMode) {
        int steering = map(receiverData.rx, 0, 254, 0, 206);
        int ssteering = constrain(steering, 60, 130);
        setServoAngle(ssteering);
        controlMotor();
      }
      lastRecvTime = millis();

      if (receiverData.js1) {
        digitalWrite(LED_F, HIGH);
        goAhead(255);
        delay(100);
      }
      if (receiverData.js2) {
        brakeMoter();
        setServoAngle(90);
        delay(200);
      }

      if (receiverData.b6 && !isSensorMode) {
        isSensorMode = true;
        angleZ = 0;
        Serial.println("Chế độ cảm biến BẬT - Cập nhật angleZ = 0");
        delay(100);
      }

      if (receiverData.b5 && isSensorMode) {
        isSensorMode = false;
        Serial.println("Chế độ cảm biến TẮT");
        delay(100);
      }

      if (receiverData.b3) {
        angleZ = 0;
      }
    }
  }
}
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
